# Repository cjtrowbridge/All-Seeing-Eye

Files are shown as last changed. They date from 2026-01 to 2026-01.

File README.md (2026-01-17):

License: 

# All-Seeing-Eye Design Document
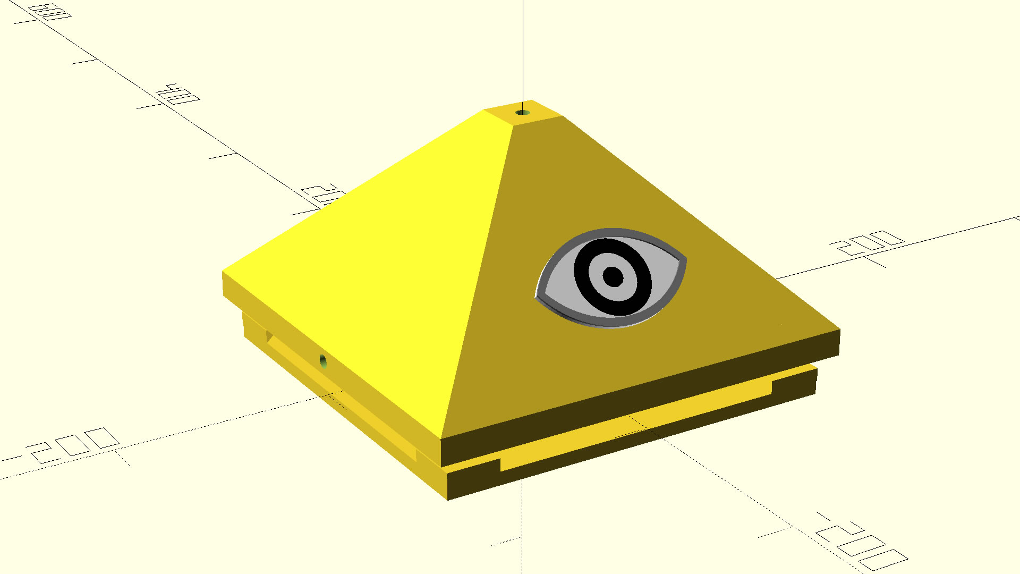
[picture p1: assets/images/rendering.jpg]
All-Seeing Eye Rendering


A 3d printed structure to contain broad spectrum sub-ghz meshtastic VLBI elements

## 1. Broader System Architecture

The overall system is composed of two primary node types:

* **SDR Node**

  * Performs wideband spectrum sensing
  * Handles coordination and task delegation
  * Synthesizes composite spectrum and RSSI bitmaps

* **All-Seeing Eye** Nodes (ESP32 + CC1101)

  * Perform distributed, narrowband RSSI sensing
  * Contribute localized observations to the global view

By correlating RSSI bitmaps from multiple perspectives, the system can simultaneously determine **where many RF broadcasts each originate from, in real time**. Complete spectral visibility emerges from the correlation of many limited observers.

This design document focuses on the **All-Seeing Eye Node** as a physical and conceptual artifact within this broader architecture.

This project is intended to operate as a **VLBI (Very Long Baseline Interferometry) Cluster**. While individual nodes provide utility, the core value proposition is the synchronized collaboration of multiple distributed nodes to triangulate signals and build high-fidelity spectrum maps.

To support synchronized sampling, nodes establish a shared wall-clock using **SNTP/NTP**. This time baseline enables cluster-wide coordination (e.g., aligned scan windows) and is a prerequisite for higher-order ranging and consensus behaviors.
When running spectrum scans, nodes should align on UTC boundaries and only sweep when `utc_seconds % 10 == 0` to keep samples phase-aligned across the cluster.

## 2. Regulatory & Operational Posture

**PASSIVE OBSERVATION ONLY**:
The "All-Seeing Eye" is designed exclusively as a **Passive Reception Device**. 
*   The default firmware strictly disables any transmission capabilities on the CC1101 radio to ensure compliance with local RF regulations (FCC/CE). 
*   The device listens, measures, and reports. It never transmits, jams, or interferes.
*   *Note: While the hardware supports TX, enabling it requires manual firmware modification by the user, who assumes all legal liability.*

---

## 3. Naming Decisions

* **All-Seeing Eye** — distributed RF observer

The term *All-Seeing Eye* is used **literally and technically**, describing emergent total visibility of the RF spectrum derived from correlated partial observations, not from a single privileged vantage point.

---

## 4. Physical Design Specifications (Prototype)

For the initial prototype, the enclosure must meet the following precise physical specifications to be modeled in 3D:

### 4.1 Base Geometry
*   **Structure**: A hollow square prism.
*   **Dimensions**: 8 inches x 8 inches (Outer footprint) - *Updated from 4" in v1.1*.
*   **Height**: 0.5 inches.
*   **Wall Thickness**: 0.25 inches.
*   **Notes**: This forms the foundation upon which the pyramid sits.

### 4.2 Pyramid Geometry
*   **Structure**: A hollow 4-sided pyramid sitting directly atop the base.
*   **Material Compatibility**: The shell must be printed in **Semi-Transparent** material (PETG/PLA) to allow internal LED diffuse lighting to be visible externally without physical apertures.
*   **Slope**: Faces must be angled at 45 degrees.
*   **Wall Thickness**: 0.25 inches.
*   **Front Face**: Blank (Eye Symbol is a separate attachment).
*   **Top**: Truncated flat top.
    *   The flat top accommodates a central SMA connector hole.

### 4.3 Base Plate (Bottom Lid)
*   **System**: A separate 0.25" thick plate that snaps into the bottom of the shell.
*   **Alignment**: Includes four corner alignment tabs (triangles) that fit inside the shell walls.
*   **Latching Mechanism**: Magnetic Latch System.
    *   **Magnets**: Uses 8x 6x3mm round magnets (4 in shell, 4 in lid).
    *   **Magnet Placement**: Magnets are installed in internal recesses (blind holes) so they never touch directly. There is a ~1mm plastic bridge separating them.
    *   **Shell Side**: Corner blocks inside the base rim hold magnets facing down.
    *   **Lid Side**: Alignment tabs hold magnets facing up.
    *   **Superglue**: Magnets are secured in their recesses with superglue or epoxy.

### 4.4 Clearances
*   The entire assembly is hollow.
*   Internal thickness of walls is consistent (0.25 inch).

### 4.5 Eye Symbol (Attachment)
*   **Design**: A separate visual artifact attached to the front face.
*   **Style**: Minimalist "All-Seeing Eye" (Almond shape + Pupil).
*   **Dimensions**: 3 inches wide x 1.75 inches tall.
*   **Mounting**: Adhered to the front 45-degree face.

---

## 5. Connectivity & Interface Layout

The connector ports are distributed across the faces of the **Base Prism** and the **Pyramid Top**.

### 5.1 Top Interface (Pyramid Apex)
*   **Connector**: VNA / Sensing SMA.
*   **Placement**: Centered on the flat, truncated top of the pyramid.
*   **Requirements**: Through-hole sized for standard SMA bulkhead. Clearance for cable attachment.

### 5.2 Base Interfaces
The base prism has four faces. The layout is as follows:

*   **Front Face**: 
    *   **Status**: Blank / Uninterrupted.
*   **Rear Face**:
    *   **Connector**: USB / Power.
    *   **Details**: A cutout or hole reaching the bottom edge of the base, allowing a USB cable to pass under/into the unit for power and control.
*   **Left Face**:
    *   **Connector**: 2.4GHz Wi-Fi Antenna (SMA).
    *   **Details**: Through-hole for SMA bulkhead. Ensure internal clearance for the nut and external clearance for antenna rotation.
*   **Right Face**:
    *   **Connector**: Meshtastic Node Antenna (SMA).
    *   **Details**: Through-hole for SMA bulkhead. Ensure internal clearance for the nut and external clearance for antenna rotation.

This layout separates sensing from networking both **electrically and visually**, while maximizing RF isolation within a compact enclosure.

---

## 6. Lighting Design

Lighting is used to convey **latent awareness**, not alerts or activity.

### Principles

* Dim, indirect, constant illumination
* No flashing, blinking, or RGB cycling
* Light is a side effect of perception, not a signal

### Lighting Layers

* **Eye Glow**: Internal RGB LED (ESP32) diffuses through the **semi-transparent shell material**. No physical hole is required.
* **Edge Leakage**: Subtle light escaping along seams or edges
* **Base Halo (optional)**: Soft downward glow to create a floating artifact effect

Lighting behavior is slow, restrained, and continuous, reinforcing the sense that the node is always perceiving.

---

## 7. Optional Hardware Components

While the core functionality is provided by the ESP32 and CC1101, additional modules can establish the node as a precise reference point in the VLBI network.

### GPS Module
*   **Component**: **[GY-NEO6MV2 (u-blox NEO-6M)](https://amzn.to/3NpCHRz)**
*   **Purpose**: Provides accurate geolocation and precise time-synchronization for signal timestamping.
*   **Precision**: +/- 2.5m.
*   **Integration**: Can be mounted internally on the base plate or adhered to the inner wall.

---

## 8. Geolocation Techniques

This section details methods for determining the positions of dispersed nodes.

### 8.0 Geolocation Core Service (Planned)
The firmware will maintain a core geolocation service that fuses evidence over time (GPS, WiFi, BLE, RF, mesh) into a single estimate. The service exposes a summarized `geolocation` block via `/api/status`, including confidence, fix type (absolute/relative), motion state, and last-updated time. This is the anchor point that BLE ranging and other sensors will feed into.

### 8.1 Native Approach (No GPS)
This method utilizes the core ESP32+CC1101 hardware to estimate location without dedicated GPS modules. It relies on a "Spring-Mass" or "Elastic Map" concept.

**1. Relative Positioning (Multidimensional Scaling)**
*   **Concept**: Every node broadcasts packets to every other node to measure pairwise RSSI (Signal Strength).
*   **Processing**: These values are fed into a **Multidimensional Scaling (MDS)** algorithm. The algorithm treats RSSI values as "springs" (distances) and unfolds the graph to find the geometric shape that best satisfies the signal constraints.
*   **Result**: A relative 2D map of where nodes are sitting relative to each other (e.g., "Node A is 5 meters left of Node B").
*   **Accuracy**: ~3–10 meters relative precision.

**2. Absolute Anchoring (WiFi Fingerprinting)**
*   **Concept**: To pin this floating relative map to the real world, ESP32s scan for all nearby WiFi Access Point BSSIDs.
*   **Processing**: This data is resolved via Geolocation APIs (e.g., Google/Mozilla) to approximate latitude/longitude.
*   **Result**: Provides an absolute "anchor" for the cluster.
*   **Accuracy**: ~15–30 meters.

**Caveats**: 
*   This approach is essentially an estimation.
*   RSSI is easily distorted by obstacles (multipath fading), which can warp the calculated geometry.
*   WiFi geolocation depends entirely on the density of known networks in the area.

### 8.2 Precision Approach (GPS)
The preferred alternative is installing the optional **GY-NEO6MV2 GPS Module** (see Section 6).
*   **Accuracy**: +/- 2.5m (Absolute).
*   **Reliability**: Independent of WiFi availability and unaffected by RF multipath distortion.

### 8.3 Role of the Single RTL-SDR
While a single RTL-SDR node cannot perform Time Difference of Arrival (TDOA) multilateration (which requires 3+ synchronized anchors), it plays a support role:
*   **Calibration**: Use the SDR to monitor transmission power of the nodes, normalizing "hot" transmitters that would otherwise skew RSSI distance calculations.
*   **Pseudo-Doppler (Advanced)**: With a custom antenna-switching add-on, the single SDR can perform Direction Finding to determine the Angle of Arrival (AoA), adding bearing lines to the location solution.

---

### 8.4 VLBI / TDOA Possibilities (Future Scope)
While the current prototype focuses on RSSI, the project name "All-Seeing Eye" references **VLBI (Very Long Baseline Interferometry)** concepts.

*   **TDOA Viability**: Time Difference of Arrival (TDOA) requires extremely precise nanosecond-level clock synchronization across nodes.
    *   **ESP32 Limitations**: The standard ESP32 clock is not stable enough for fine-grained TDOA on its own.
    *   **Non-Coherent Operation**: Since the nodes are not phase-coherent (they don't share a local oscillator), standard interferometry is impossible.
*   **Large Baseline Approach**: If nodes are separated by significant distances (kilometers), the timing requirements relax slightly for macroscopic TDOA.
    *   **GPS PPS**: Adding the **GPS Module (Section 6)** provides a **Pulse Per Second (PPS)** signal. This can discipline the local clocks to within microsecond accuracy.
    *   **Feasibility**: With GPS-disciplined timestamps, TDOA could potentially resolve location to within ~300 meters (1 microsecond = ~300m light travel time). This allows for "City-Scale" triangulation of powerful signal sources, staying true to the VLBI inspiration despite the lack of phase coherence.

### 8.5 Mesh-Assisted Localization (Opportunistic)
If the node is operating within an active Meshtastic mesh, it can utilize traffic from *other* nodes to determine its own location.

*   **Mechanism**: The node listens for position packets from nearby Meshtastic nodes that *do* have GPS fixes.
*   **Calculation**: By measuring the RSSI of the incoming packet and extracting the GPS coordinates from the payload, the node treats the sender as a "Beacon" or "Anchor".
*   **Trilateration**: With signals from 3+ distinct GPS-enabled peers, the node can estimate its position based on expected signal fade (Path Loss Models).
*   **Single-Hop Constraint**: This technique relies on **direct (single-hop)** reception. Use of RSSI from relayed packets would result in calculating distance to the repeater, not the original sender, leading to gross errors. The system must verify the packet has not been hopped before using it for ranging.

### 8.6 BLE Ranging & Live Topology Consensus
To complement RF triangulation, newer iterations of the system employ BLE (Bluetooth Low Energy) for high-resolution proximity detection within the cluster itself.

*   **Stationarity Detection**: By constantly monitoring the RSSI of known peers over BLE, the cluster can detect if the configuration is static or in motion. Stable RSSI values over N minutes imply a stationary deployment, triggering higher-precision, longer-integration RF tasks.
*   **Short-Range Ranging (<20m)**: Standard WiFi/Sub-GHz RSSI is noisy. BLE advertising provides a separate, dedicated channel for "Ranging Beacons".
    *   **Consensus**: If Node A sees Node B at -40dBm and Node C at -85dBm, and Node B sees Node C at -70dBm, the cluster can solve for the relative geometry of the triangle {A,B,C}.
*   **Implementation**: This runs as a background task (`SystemIdlePlugin`) on the ESP32 core, independent of the CC1101 radio, ensuring it does not interrupt long-range spectral monitoring.

---

## 9. Overall Intent

The All-Seeing Eye Node is designed as:

* a sensing instrument
* a symbolic artifact
* a field-deployable system component

The system observes **broadcast signals, not people**. Power derives from distribution, correlation, and persistence rather than authority or control.

The object is meant to feel present, inevitable, and quietly capable — something you notice after it has already been there.

---

## 10. Locked Concepts

* **Names**: SDR Node, All-Seeing Eye Node, All-Seeing Eye View
* **Form**: Pyramidal structure on a raised square base.
* **Function**: Distributed RF visibility through correlated RSSI sensing
* **Aesthetic**: Ominous, restrained, archetypal, intentional

---

## 11. Fabrication & Build Pipeline

The physical enclosure is designed programmatically using **OpenSCAD**. This ensures that all dimensions, clearances, and tolerances can be adjusted parametrically and versioned as code.

### Prerequisites
*   **OpenSCAD**: Download and install from [openscad.org](https://openscad.org/).

### Shopping List
* Sparkly semi-transparent purple PLA filament ([$19.99](https://amzn.to/3Yy0ZLC))
* I used an AD5M Pro 3D printer which is 10/10. Fully enclosed and filtered. 220x220x250mm build volume. Very easy to use. ([$379](https://amzn.to/4aUHjsQ))
* ESP-32 3-pack with IPX MHF1 connector ([$17.99](https://amzn.to/3YyJqLl))
* CC1101 module 3-pack ([$22.99](https://amzn.to/4qEJl4S))
* IPX MHF1 to SMA Cable 5-pack ([$8.29](https://amzn.to/3NbLDdm))
* Jumper wires (male-female) (there are infinite options here but there are what i used) ([$6.98](https://amzn.to/4qsRIkg))
* Heltec v3 Meshtastic Node (optional, any meshtastic node with IPX MHF1 connector will do) ([$21.99](https://amzn.to/49MXC9Y))
* GY-NEO6MV2 GPS Module (optional) ([$9.99](https://amzn.to/3NpCHRz))
* 2.4ghz wifi antenna 4-pack (optional, any wifi antenna with SMA connector will do) ([$8.69](https://amzn.to/4szIt3d))
* 915mhz antenna 2-pack (optional, any 915mhz antenna with SMA connector will do) ([$9.99](https://amzn.to/3LGUaV7))
* SMA Extensions 2-pack (optional, but its going to hard to fit everything without these [$6.99](https://amzn.to/45Ou0Xd))
* Self-advesive breadboard (optional) [$8.99](https://amzn.to/49mhwbJ)

### Source Files
*   Design files are located in the `3d models/design/` directory.

#### Core Files
*   **Shell (Blank)**: `3d models/design/all-seeing-eye.1.6.scad` (Magnetic Latch System, Blank Face).
*   **Base Plate**: `3d models/design/base-plate.1.0.scad` (Matching Magnetic Lid).
*   **Eye Symbol**: `3d models/design/eye-symbol.1.0.scad` (Separate print).

#### Combined Variants
*   **Combined Shell**: `3d models/design/combined-1.1.scad` (Shell + Eye formed as one piece. **Includes transparency cutout** behind the eye for LED visibility).

#### Visualization
*   **Assembly**: `3d models/design/assembly.1.0.scad` (Visualization only).

### Printing Strategies
You can choose between two assembly methods:

1.  **Combined Print (Recommended)**: 
    *   Print `combined-1.1.stl` and `base-plate.1.0.stl`.
    *   This provides a robust, single-piece shell with the eye symbol pre-integrated and optimized for transparency.
2.  **Separate Parts**:
    *   Print `all-seeing-eye.1.6.stl` (Blank Shell), `eye-symbol.1.0.stl`, and `base-plate.1.0.stl`.
    *   Glue the eye symbol onto the front face manually.
    *   *Note*: This method does not have the transparency cutout behind the eye, so the LED glow may be dimmer.

### Generating 3D Printable Files (STL)
To generate the STL files for printing:

1.  Run the automated build script:
    ```cmd
    cd "3d models"
    .\build.bat
    ```
2.  The script will automatically detect OpenSCAD and compile all versions found in the `design/` folder.
3.  Output STL files will be placed in the `build/` directory.

### Print Preview & Estimates
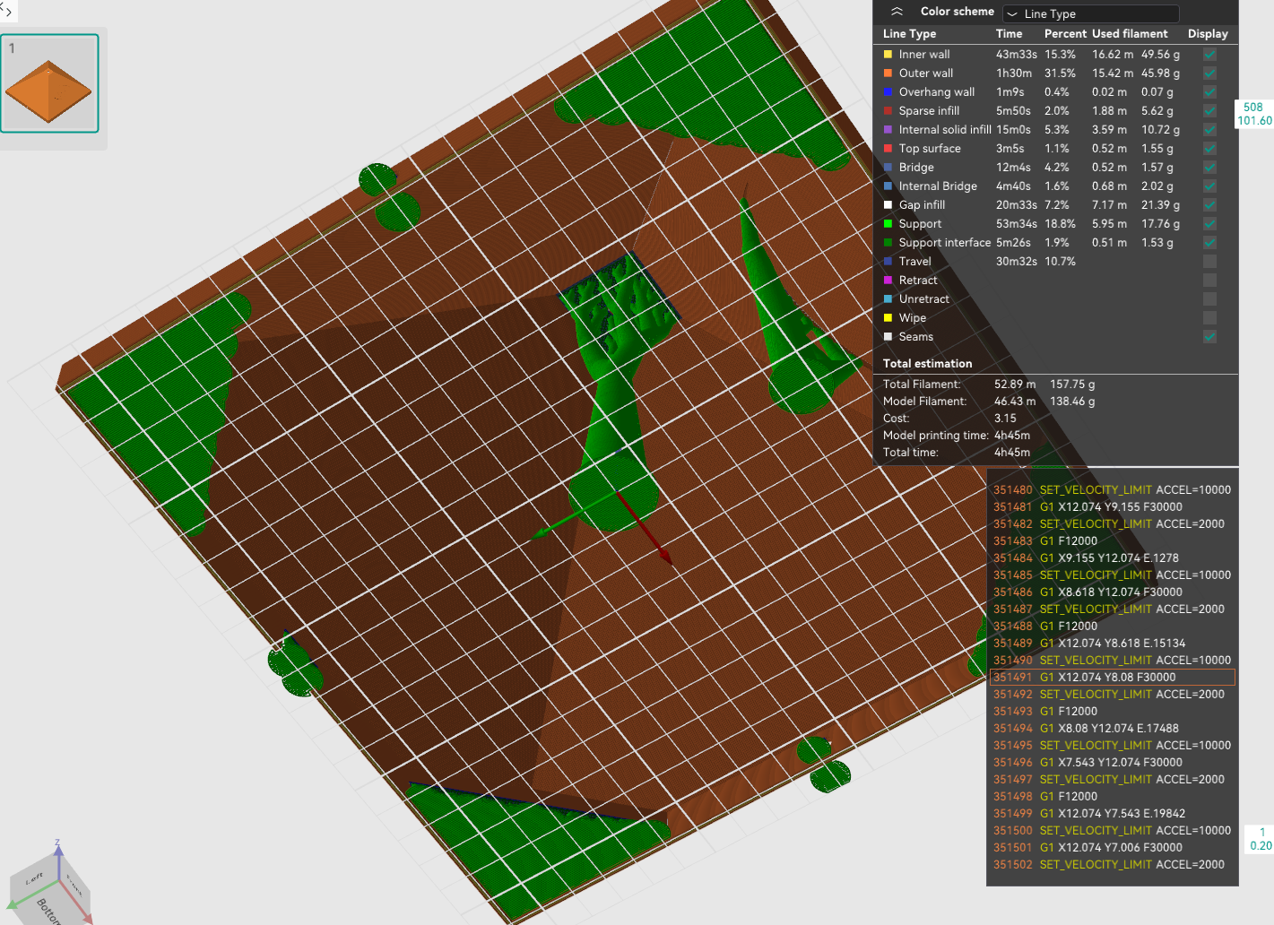
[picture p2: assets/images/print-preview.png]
Print Preview


(Note: Estimates below are approximate place holders based on 15% infill and standard PLA settings with tree support).

*   **Print Time**: 4 hours, 45 minutes
*   **Material Usage**: ~157.75g
*   **Material Cost**: ~$3.15 (at $19.99/kg)

---

## 12. Wiring Guide (ESP32-S3 N16R8)

The system uses an **ESP32-S3-WROOM-1 N16R8** development board. This board has a different pinout than the classic ESP32.

The recommended wiring uses the **Left Header** almost exclusively to keep cabling tidy, and because thats all you can access in a standard breadboard with a package this size. It utilizes the default hardware SPI pins for the S3 (FSPI).

| CC1101 Pin | Pin Name | Function | ESP32-S3 Pin | Location on Board |
| :--- | :--- | :--- | :--- | :--- |
| 1 | **GND** | Ground | **GND** | Bottom Left (G) |
| 2 | **VCC** | Power (3.3V) | **3V3** | Top Left (Pin 1 or 2) |
| 3 | **GDO0** | Interrupt (Differs from v1) | **GPIO 4** | Left Side (Top) |
| 4 | **CSN** | Chip Select | **GPIO 10** | Left Side (Middle, marked FSPICS0) |
| 5 | **SCK** | SPI Clock | **GPIO 12** | Left Side (Middle, marked FSPICLK) |
| 6 | **MOSI** | Master Out | **GPIO 11** | Left Side (Middle, marked FSPIIO5) |
| 7 | **MISO** | Master In | **GPIO 13** | Left Side (Middle) |
| 8 | **GDO2** | Interrupt 2 (Optional) | **GPIO 5** | Left Side (Top) |

### Additional Hardware Notes
*   **Onboard RGB LED**: The built-in status LED on this specific board is on **GPIO 47** (or 48 on some variants).
*   **Power & Programming**: 
    *   **Right Port (UART)**: Use this for standard programming and serial monitoring. It runs through the onboard CH343P chip for a reliable connection.
    *   **Left Port (USB)**: This is the native ESP32-S3 USB (OTG) port. It can power the board, but is used for advanced USB device emulation.
*   **Antennae**: Ensure the CC1101 antenna is connected before powering on the device to avoid damage to the PA (Power Amplifier).

---

## 13. Version History & Development Log

This section documents the iterative design process from initial concept to the current printable shell.

### Current Version: v1.6 (Magnetic System)
*   **Status**: Ready for Print.
*   **Description**: Full magnetic latching enclosure system.
*   **Components**:
    1.  **Shell (v1.6)**: Added internal corner blocks with blind holes for 6x3mm magnets.
    2.  **Base Plate (v1.0)**: New bottom lid with alignment tabs and matching magnet recesses.
    3.  **Eye Symbol (v1.0)**: Separate "Vesica Piscis" style eye attachment.
    4.  **Combined Variant (v1.0)**: Alternate shell model with the Eye Symbol already fused to the front face (single print).
*   **Material**: Shell MUST be printed in **Semi-Transparent** material for checking internal status LEDs without opening.

### Development Milestones

*   **v1.5**: Clean Shell.
    *   Reverted complex internals to validate form factor.
    *   8-inch base, 45-degree slope.

*   **v1.3 - v1.4**: Internal Mounting Experiments (Deprecated).
    *   Analyzed ESP32-S3-WROOM-1-N16R8 dimensions via photos.
    *   Measured LED alignment offsets (-6mm X, +18mm Y) to center the LED on the pyramid face.
    *   Designed candidate internal brackets for "flush face" mounting.
    *   *Decision*: Complexity of supporting floating internal rails was high; reverted to clean shell (v1.5) to ensure printability first.

*   **v1.2**: Geometry Fixes.
    *   Identified and fixed a bug where the internal hollow void was cutting completely through the roof.
    *   Adjusted the inner pyramid height to leave a solid 0.25" roof for the top SMA connector.

*   **v1.1**: Scaling Up.
    *   Increased base size to 8 inches to accommodate larger internal volume requirements.
    
*   **v1.0**: Initial Parametric Design.
    *   Established the OpenSCAD codebase.
    *   Defined the core "Base + Pyramid" geometry.
    *   Initial size: 4-inch base.

### Hardware Research (ESP32-S3)
*   **Device**: ESP32-S3-WROOM-1-N16R8 Dev Board.
*   **Dimensions**: 58mm x 28mm (PCB footprint).
*   **LED Position**: The RGB LED is offset from the center.
    *   **X-Offset**: ~6mm left of PCB center.
    *   **Y-Position**: ~18mm from the USB edge.
*   **Future Integration**: Future enclosure revisions will incorporate a mounting sled or clip that aligns this specific LED location with a window in the pyramid face.

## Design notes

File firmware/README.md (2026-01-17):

# Developer Protocol & Tips
**Critical instructions for Agent/Devs to avoid build loops:**

1.  **Build System Limitations**: 
    -   Arduino's build system struggles with complex relative paths in `#include`. 
    -   **Rule**: Keep all header files flat in `src/` (e.g., `src/CC1101Plugin.h`, not `src/plugins/radios/CC1101Plugin.h`). Complexity is managed by namespaces, not folders.

2.  **Build Automation**:
    -   **Never** manually run `arduino-cli` commands in the terminal. The syntax is brittle on PowerShell.
    -   **Rule**: Always use `.\upload_ota.bat`. It handles library paths and OTA upload arguments reliably.

3.  **Concurrency (Dual Core)**:
    -   Core 0 (System) and Core 1 (Plugin) share resources.
    -   **Rule**: Always use `xSemaphoreTake` with a timeout (e.g., `pdMS_TO_TICKS(100)`) when accessing shared objects (like the Plugin pointer). Never block indefinitely.

4.  **Logging & Debugging**:
    -   **Rule**: Do NOT create ad-hoc text files (e.g., `output.txt`, `debug.txt`) in the repo. They clutter the git history.
    -   **Rule**: If you must dump output to a file, use the `.log` extension (e.g., `build.log`), as these are globally ignored by `.gitignore`.
    -   **Rule**: Log timestamps use the configured device timezone (NTP-synced) and fall back to Unix epoch seconds before sync. Startup head logs include the applied timezone.

5.  **Regulatory Compliance (NO TX)**:
    -   **Rule**: The CC1101 radio must be operated in **RX (Receive) Mode ONLY**.
    -   **Rule**: Do not commit any code that initializes the radio for transmission (TX) or enables broadcasting. The default firmware is passive.

6.  **WebUI Polling Optimization**:
    -   **Rule**: The WebUI must only poll `/api/status` on a regular interval (e.g., 2s).
    -   **Rule**: `/api/status` must embed the latest **Logs** (last N lines) and **Peer List** to support this single-call architecture.
    -   **Reason**: The ESP32 single-core network stack struggles with concurrent HTTP requests. reducing connection overhead improves responsiveness.

# Hardware Abstraction Layer (HAL)

The firmware is designed to run on diverse hardware configurations. The `HAL` class manages driver initialization and sets Capability Flags based on Power-On Self Tests (POST).

The System Kernel uses these flags to determine which tasks can be run. These flags are exposed via `/api/status` so external agents can make informed decisions.

*   `cc1101`: (bool) True if the Sub-GHz radio was detected and initialized successfully on the SPI bus.
*   `gps`: (bool) True if a dedicated hardware GPS module is connected (UART).
*   `meshtastic`: (bool) True if a LoRa radio is available for Meshtastic interoperability.

# Cluster Task Coordination

The cluster coordinates tasks using **status-based alignment**. Nodes do **not** push task payloads to peers. Instead, each node advertises its desired task in `/api/status`, and peers align themselves by observing the network.

*   **Desired Task**: `/api/status.desired_task` contains the staged task payload.
*   **Start Gate**: `/api/status.start_requested` signals when execution should begin.
*   **Alignment Rule**: The WebUI enables the Start button when `/api/peers` shows that all online peers have aligned to the desired task.
*   **Memory**: Results are ephemeral and cleared when the task changes.

---

# Roadmap

## Phase 1: Core Framework (Completed)
- [x] Basic ESP32-S3 Board Support
- [x] Double-Buffered Plugin Architecture (Core 0 vs Core 1)
- [x] RingBuffer for high-speed logging
- [x] OTA via `espota`
- [x] Webpack pipeline for embedded `index.html`

## Phase 2: Hardware Drivers (Completed)
- [x] CC1101 SPI Integration
- [x] RSSI Reading & Tuning
- [x] Circular Buffer Logging

## Phase 3: Web Dashboard (Completed)
- [x] Basic SPA structure
- [x] WebSocket/Poll-based logs
- [x] **UI Refactor v2 (Jan 2026)**: 
    -   Implemented 3-column "Desktop" layout (Environment / Task List / Execution).
    -   Center column functions as the primary Control interface with a categorized **Task List**.
    -   Tasks are grouped by Plugin (human-readable headers) for better navigability.
- [x] **Navbar Enhancements**: Cluster Status with "Sparkle" indicators.

# Web Interface Architecture

## Layout System
The WebUI (`index.html`) uses a responsive grid layout that adapts between mobile and desktop views:

1.  **Environment (Left)**:
    -   **Cluster Tree**: Shows local and remote nodes, grouped by cluster name.
    -   **Topology Map**: Force-directed graph of the mesh network.
    -   **Logs**: Dual-tab monitor for `Tail` (Live) and `Head` (Boot) logs.

2.  **Controls (Center)**:
    -   **Task List**: The primary catalog of available operations (Plugins).
        -   Grouped by **Plugin Name** (e.g., "System", "Spectrum Analyzer").
        -   Tasks are defined in `PluginManager.cpp` and served via `/api/task`, including input schemas.
    -   **Device Config**: Settings for Hostname, Identity, Timezone, and LED.

3.  **Workspace (Right)**:
    -   **Input Form**: Dynamically generated based on the selected task's requirements.
    -   **Execution State**: Shows live status, spinners, and timers during task execution.
    -   **Results**: (Planned) Dedicated view for post-mission data analysis.

## Development Workflow
The WebUI is a single-file application (`firmware/web/index.html`). To modify it:

1.  Edit `firmware/web/index.html`.
2.  Run `pack_web.py` (in `firmware/`) to compress the HTML into `WebStatic.h` (Gzip + Hex).
3.  Compile and upload firmware using `upload_ota.ps1`.

**Note**: The ESP32 does not serve the file from a filesystem; it serves the byte array from flash memory for speed and reliability.

# Web Interface & Topology Map

The Web Dashboard (`/index.html`) includes a live **Topology Map** visualizing the mesh network.

## Legend Reference

| Element | Color | Description |
| :--- | :--- | :--- |
| **Self (Dot)** | `Cyan (#03dac6)` | The node currently hosting the web interface. |
| **Peer (Dot)** | `Purple (#bb86fc)` | A peer node that is currently **Online** and responsive. |
| **Offline (Dot)** | `Gray (#444)` | A peer node that has timed out (stale) or is unresponsive. |
| **LAN Link** | `Blue (#2196F3)` | A direct network connection (WiFi or Wired) established via mDNS discovery. |
| **Ranging** | `Red (#cf6679)` | (Planned) A physical RF ranging measurement between nodes. |

## Interaction

*   **Click Node**: Navigate to that node's WebUI (`http://[hostname].local`).
*   **Hover**: View tooltip (currently hostname).
*   **Physics**: The map uses a force-directed graph (d3-style) where nodes repel each other but are bound by links.

# Roadmap Continued

## Phase 4: VLBI Clustering (Backend Completed)
- [x] **Core Logic**: Default Kernel state is now `SystemIdle` (POST -> Idle).
- [x] **Unique Identity**:
    - [x] Hostnames: `allseeingeye-{hexid}.local` (from MAC address).
- [x] **Time Synchronization (Foundation)**:
    - [x] **SNTP Integration**: 
        - [x] Configure `configTime` with `pool.ntp.org` and proper timezone handling (Los Angeles).
        - [x] Implement `Kernel::isTimeSynced()` validator (Checks Year > 2025).
        - [x] Enable time zone configuration via `/api/config` (string, e.g., "America/Los_Angeles") and persist in NVS
        - [x] Map common IANA timezones to POSIX TZ rules for localtime/log formatting.
        - [x] Make timezone editable in webui under device tab.
    - [x] **API Visibility**: 
        - [x] Add `time` (Unix Epoch) and `ntp_sync` (bool) to `/api/status`.
    - [x] **Drift Management**: 
        - [x] Configure re-sync interval (1hr).
- [x] **Discovery Protocol**:
    - [x] **Zero-Conf**: mDNS (`_allseeingeye._tcp`) auto-discovery.
    - [x] **Subnet Scanning**: Automatically scans local /24 subnet (1-254) if isolated.
    - [x] **Passive Discovery**: Intercepts requests to `/api/peers` to find new neighbors.
    - [x] **Negative Caching**: Ignores non-peer IPs for 12h to reduce network noise.
- [x] **Cluster Management**:
    - [x] Nodes advertise `cluster` text record in mDNS.
    - [x] Clusters visualized in Web UI Tree View.
    - [x] Configurable **Cluster Name** and **Ignore Hours**.

## Phase 5: Task-Oriented Architecture (In Progress)
The system has pivoted from always-on background services to an On-Demand Task Architecture to respect ESP32 resource constraints.

### 5.1 The Task Registry (Framework)
- [x] **Plugin Framework**:
    - [x] `ASEPlugin`: Abstract base class implementation.
    - [x] `PluginManager`: Handles loading/unloading and exclusive resource locking.
    - [x] **Discovery API (`GET /api/task`)**: Returns catalog of available tasks.
        - [x] Grouped by Plugin Name.
        - [x] Includes Task ID, Description, Link, and `inputs` schema.
- [x] **Task Execution API**:
    - [x] `POST /api/task/{taskId}`: Submits parameters and starts execution.
        - [x] **UX Flow**: Response replaces the UI "Working" container with results table/heading.

### 5.2 WebUI Implementation (Task Runner)
The Web Interface must dynamically render available tasks and handle the execution flow.
- [x] **Catalog Rendering (Navigation)**:
    - [x] Fetch catalog from `GET /api/task`.
    - [x] Render groupings by Plugin Name (e.g., `<h3>BLE Ranging</h3>`).
    - [x] Render buttons for each task under the appropriate heading.
- [x] **Dynamic Form Generation (Task Panel)**:
    - [x] **Action**: Clicking a task button reads the `inputs` schema from the cached `/api/task` catalog.
    - [x] **Render**: Clear the Task View (Right/Center Column) and generate an HTML Form based on the schema.
    - [x] **Validation**: Ensure required fields are marked and validated before submission.
- [x] **Execution State**:
    - [x] **Submission**: On form submit, serialize data to JSON.
    - [x] **UI Update**: Remove Form -> Display "Deploying..." / Spinner message.
    - [x] **Request**: Send `POST /api/cluster/deploy` with task payload.
- [x] **Result Rendering**:
    - [x] **Execution**: Start is enabled only after cluster alignment; UI calls `POST /api/cluster/start`.
    - [x] **Report View**: UI polls `/api/report` and renders JSON output.

### 5.3 Geolocation (On-Demand Plugin)
Moved from background service to requested task.
- [ ] **Features**:
    - [ ] `Fix Acquisition`: Power up GPS (if avail) or run WiFi/BLE anchor scan. High power usage.
    - [ ] `Motion Baseline`: Short sampling period to detect movement vectors.
    - [ ] `Confidence Recalibration`: Re-assess cached location vs new signals.
- [ ] **Architecture**:
    - [ ] Plugin owns the Geolocation State.
    - [ ] Results persist in `/api/status` (cached) after task completes.

---

# Phase 6: Core Plugins (Detailed Plan)
The following plugins will be implemented using the new Task Registry framework.

- [ ] **6.1 BLE Ranging Plugin**
## 6.1 BLE Ranging Plugin
*   **Heading**: BLE Ranging
*   **Tasks**:
    1.  [ ] **Peer Ranging**:
        *   [ ] *Endpoint*: `/api/task/ble-ranging/peer`
        *   [ ] *Inputs*: Duration (ms), Target Peer (Optional).
        *   [ ] *Action*: Active scan + RSSI history logging.
    2.  [ ] **Device Survey**:
        *   [ ] *Endpoint*: `/api/task/ble-ranging/survey`
        *   [ ] *Inputs*: Scan Window (ms), Filter (Manufacturer/Service).
        *   [ ] *Action*: Lists all nearby BLE MACs and payloads.

- [ ] **6.2 Geolocation Plugin**
## 6.2 Geolocation Plugin
*   **Heading**: Geolocation
*   **Tasks**:
    1.  [ ] **Fix Acquisition**:
        *   [ ] *Endpoint*: `/api/task/geolocation/fix`
        *   [ ] *Inputs*: Timeout (ms), Desired Accuracy (m).
        *   [ ] *Action*: Aggregates GPS + WiFi anchors. Returns Lat/Lon/Alt.
    2.  [ ] **Motion Baseline**:
        *   [ ] *Endpoint*: `/api/task/geolocation/motion`
        *   [ ] *Inputs*: Sample Duration (s).
        *   [ ] *Action*: Detects if node is stationary or moving.
    3.  [ ] **Confidence Recalibration**:
        *   [ ] *Endpoint*: `/api/task/geolocation/recalibrate`
        *   [ ] *Action*: Checks current fix against new evidence without full acquisition.

- [ ] **6.3 RF Diagnostics Plugin**
## 6.3 RF Diagnostics Plugin
*   **Heading**: RF Diagnostics
*   **Tasks**:
    1.  [ ] **Noise Floor Check**:
        *   [ ] *Endpoint*: `/api/task/rf-diag/noise`
        *   [ ] *Inputs*: Frequency Band (e.g., 915MHz).
        *   [ ] *Action*: Measures RSSI without sync word/packet logic.
    2.  [ ] **RSSI Snapshot**:
        *   [ ] *Endpoint*: `/api/task/rf-diag/rssi`
        *   [ ] *Action*: Quick sample of ambient energy.
    3.  [ ] **Antenna Health Check**:
        *   [ ] *Endpoint*: `/api/task/rf-diag/antenna`
        *   [ ] *Action*: (Experimental) Heuristic check of VSWR proxy (if HW supports) or signal consistency.

- [ ] **6.4 Spectrum Analysis Plugin**
## 6.4 Spectrum Analysis Plugin
*   **Heading**: Spectrum Analysis
*   **Tasks**:
    1.  [x] **Band Scan**:
        *   [x] *Endpoint*: `/api/task/spectrum/scan`
        *   [x] *Inputs*: Start Freq, Stop Freq, Step.
        *   [x] *Action*: Standard sweep, returns CSV/JSON array of power levels.
        *   [x] *Sync Rule*: Sweep only when `utc_seconds % 10 == 0` so clusters sample in lockstep.
        *   [x] **CC1101 Limits**:
            - [x] Frequency bands: 300–348 MHz, 387–464 MHz, 779–928 MHz
            - [x] Bandwidth: 58–812 kHz
            - [x] Power: -30 to +10 dBm
            - [x] Defaults: 905–928 MHz, 500 kHz, -1 dBm
    2.  [ ] **Peak Hold Sweep**:
        *   [ ] *Endpoint*: `/api/task/spectrum/peak`
        *   [ ] *Inputs*: Duration.
        *   [ ] *Action*: Runs multiple sweeps, keeping only max values.
- [ ] **6.5 Meshtastic Surveillance Plugin**
## 6.5 Meshtastic Surveillance Plugin
*   **Heading**: Meshtastic Surveillance
*   **Tasks**:
    1.  [ ] **Traffic Monitor**:
        *   [ ] *Endpoint*: `/api/task/meshtastic/monitor`
        *   [ ] *Inputs*: Duration, Channel Index.
        *   [ ] *Action*: Logs all seen packets with RSSI/SNR metrics to identify active talkers.
    2.  [ ] **Origin Ranging**:
        *   [ ] *Endpoint*: `/api/task/meshtastic/ranging`
        *   [ ] *Inputs*: Target Node ID.
        *   [ ] *Action*: Analyzes signal strength and hop counts of incoming messages to estimate physical proximity.
    3.  [ ] **Network Traceroute**:
        *   [ ] *Endpoint*: `/api/task/meshtastic/trace`
        *   [ ] *Inputs*: Target Node ID.
        *   [ ] *Action*: Performs an active traceroute to map the hop path and locate the node within the mesh topology.

---

## Phase 7: Telemetry & Peripheral Expansion
- [ ] **Hardware Probe**:
    - [ ] **Serial Probe**: Detect attached GPS (NMEA) or Meshtastic node on boot.
    - [ ] **I2C Scanner**: Auto-detect connected environment sensors (Temp, Air Quality, Geiger).
- [ ] **Meshtastic Integration**:
    - [ ] Serial API Client: Send/Receive messages via attached mesh node.
    - [ ] Configurable Channel: "Announce to Public" vs "Private Group".
- [ ] **Universal Telemetry Bus**:
    - [ ] Standardized polling for arbitrary sensors.
    - [ ] User-configurable announcement intervals.

## Phase 8: Distributed Coordination
- [ ] **Advanced Synchronization (VLBI)**:
    - [ ] **Microsecond Precision**: Track sub-second drift against GPS PPS if available.
    - [ ] **Multi-Transport Sync**: Support sync via Wi-Fi (NTP/PTP) and Meshtastic/LoRa (Custom Beacon).
    - [ ] **Latency Compensation**: Measure RTT (Round Trip Time) to compensate for transmission delay/light-speed lag across different mediums.
    - [ ] **Drift Correction**: Continuous adjustment for local clock drift relative to cluster consensus.
- [ ] **Sychronized Scanning**: Cluster leader designates frequency sweep windows and satart times, based on precisely synchronized time.
    - [ ] **Current Rule**: Spectrum sweeps trigger only when `utc_seconds % 10 == 0`.
- [ ] **TDOA/RSSI Triangulation**: Aggregating data from the cluster to locate the sources of many broadcasts seen simultaneously in a sweep.

## Phase 9: Mesh Parity (Transport Independence)
- [ ] **Transport Agnosticism**: API, Telemetry, and Cluster Control must function transparently over both Wi-Fi and Meshtastic.
- [ ] **Remote Node Equivalence**: A remote node on the mesh should appear in the local Cluster UI just like a Wi-Fi peer.
- [ ] **Bandwidth Optimization**: Protocol compression to support full C2 (Command & Control) over low-bandwidth LoRa links. Since commands are small and text-based, this is highly feasible.

---

# Application Architecture: The VLBI Cluster

## 1. Identity & Discovery (Implemented)
To function as a swarm, every node needs a unique identity on the network.
- **Hostname**: `allseeingeye-XXXXXX`, where `XXXXXX` is the last 3 bytes of the MAC address.
- **Discovery Hierarchy**:
    1.  **mDNS**: Primary method. Multicast announcement of `_allseeingeye._tcp`.
    2.  **Viral/Passive**: When Node A talks to Node B, Node B checks Node A.
    3.  **Brute Force**: If a node has 0 peers, it sequentially scans the entire `.1` to `.254` subnet looking for friends.
- **API Endpoints**:
    -   `/api/peers`: Returns list of known neighbors and their cluster/status.
    -   `/api/ping?target={ip}`: Manual connectivity check.
    -   `/api/config`: Set `cluster` name to move devices between groups.
    -   `/api/status`: Returns system health + current implementation details.

## 2. The concept of "Clustering"
Nodes are not solitary actors; they are members of a **Cluster**.
- **Default State**: Out of the box, all nodes belong to the cluster named `"Default"`.
- **Behavior**: All nodes in a cluster share the same configuration.
- **Formation**: A user can change a node's Cluster Name via the Web UI (or API). That node logically separates and begins listening for peers with the matching Cluster Name.

## 3. The User Interface (Zero-Conf)
The Web UI is hosted on *every* node, but any node can visualize the *entire* cluster.

**Layout Structure:**
1.  **Navbar**:
    *   Branding ("All-Seeing Eye")
    *   Connection Status (Online/Offline)
    *   Cluster Status: `Current Cluster: Default ✨ Working On: SystemIdle ✨`
2.  **Main Content Area (Tabbed View)**:
    *   **Clusters**: Tree view of all clusters and nodes (Auto-Grouping).
    *   **Task View**: Current operation controls (Scanner/Monitor) and task status.
    *   **Logs**: Real-time scrolling system logs (RingBuffer backed).
3.  **Visualization Panel**: Persistent spectrum analysis canvas (bottom of screen).
4.  **Footer**: Telemetry (RAM, Uptime) & Version info.

**Tabs Detail:**
1.  **Cluster Tab (Functional)**:
    -   A Tree View of all announced clusters on the subnet.
    -   `> Default Cluster`
        -   `allseeingeye-a1b2c3` Independent Exploration [Ready]
        -   `allseeingeye-f453a4` Hardware Verification [Working]
    -   `> Scanner-Group-1`
        -   `allseeingeye-224466` RSSI Sweep [Working]

2.  **Node Drill-down**:
    -   Clicking a node opens that device's dashboard.
    -   **Tooltip**: Hovering over a node displays exact task details.

## 4. Task Awareness (New)
The cluster is now "Task Aware".
-   **Default Task**: "Independent Exploration" (System Idle).
-   **Visibility**: All nodes broadcast their current high-level task via `/api/status`. 
-   **Logic**:
    -   `SystemIdlePlugin` -> "Independent Exploration".
    -   `RadioTestPlugin` -> "Hardware Verification".
    -   Future plugins will define their own strings (e.g., "Spectrum Sweep 900-928MHz").
-   **UI Representation**: 
    -   Format: `Hostname | Task Name | [Status]`
    -   Example: `allseeingeye-f453a | RSSI Scanning | [Working]`

## 5. Configuration Fields
To support this, the global configuration structure must expand:
```cpp
struct Config {
    char wifiSSID[32];
    char wifiPass[64];
    // ... current fields ...
    
    // Identity
    char clusterName[32];       // Default: "Default"
    char nodeDescription[255];  // Default: "New Node" or Empty
};
```

## 6. Radio Task Queue Architecture

To support complex operations (scanning, replaying, jamming) while maintaining cluster synchronization, the system moves from a "State Machine" model to a "Scheduled Task" model.

### 6.1 The "Singleton Radio" Problem
The CC1101 radio is a shared resource that cannot do two things at once. It cannot "listen for commands" while "scanning spectrum." Therefore, access must be arbitrated by a **Scheduler**.

### 6.2 Task Object Structure
A `RadioTask` is a self-contained unit of work:
*   **UUID**: Unique identifier for API tracking.
*   **Type**: `CRITICAL` (Startup), `CLUSTER` (Sync), `USER` (API), `BACKGROUND` (Idle).
*   **Plugin**: The specific logic to run (e.g., `Plugin::SpectrumSweep`).
*   **Parameters**: Frequency, duration, target settings.

### 6.3 Lifecycle & Boot Stages
The node does not immediately start "working" on boot. It follows a strict initialization path:

1.  **Phase 1: POST (Power-On Self Test)**
    *   Hardware Init, Filesystem Mount, Config Load.
    *   **Peripheral Probe**: Scan I2C/UART for GPS or Meshtastic nodes.
2.  **Phase 2: Infrastructure**
    *   Wi-Fi Connect, mDNS Start, HTTP Server Start, **NTP Sync**.
    *   **Telemetry Init**: Register any other discovered sensors.
3.  **Phase 3: Startup Queue (Calibration)**
    *   The `Scheduler` is pre-loaded with critical tasks:
    *   1. `RadioHardwareTest`: Ensure SPI comms.
    *   2. `GeolocationScan`: Fingerprint environment.
    *   3. `BackgroundNoiseCalibration`: Measure local RF noise floor.
    *   *(Note: Cluster Discovery is strictly Wi-Fi or Meshtastic Serial; no CC1101 beaconing by default)*.
4.  **Phase 4: Operational Loop**
    *   The Scheduler processes `Queue[0]`.
    *   If Queue is empty -> Insert `IdleTask` (e.g., Background Scan).

### 6.4 API Integration
*   **Enqueue**: Agents/Users `POST` tasks to `/api/queue`.
*   **Preemption**: High-priority tasks (User overrides) push current tasks to `PAUSED` or `ABORTED` state.
*   **Visibility**: `/api/status` returns the current queue depth and next scheduled operation.
*   **Self-Correction**: All API errors must return a `usage` key with a valid JSON example to allow Agents to retry automatically.
*   **Abort to Idle (WebUI)**: The WebUI abort action deploys `system/idle` via `/api/cluster/deploy` followed by `/api/cluster/start` to return the cluster to idle.

## 7. Cluster Network Topology Visualization
The Web UI includes a "Network Map" canvas to visualize the complex relationships between nodes, especially as we introduce varied transport layers (Wi-Fi, Meshtastic, VPN).

### 7.1 The Graph Model
*   **Vertices (Nodes)**: Each node (local or remote) is a vertex.
*   **Edges (Connections)**: A connection represents a visibility path.
    *   *Wi-Fi (LAN)*: Typically a full mesh (everyone sees everyone).
    *   *Meshtastic (LoRa)*: Partial mesh; Node A might see B, but A might not see C directly (multi-hop).
    *   *VPN*: Long-distance links connecting disparate subnets.
    *   *Indirect*: Connections reported by a peer that the local node cannot see directly.

### 7.2 Link Types (Edge Coloring)
The visualization distinguishes different types of relationships between nodes using color coding:

*   **Blue Links (Peer Visibility)**: 
    *   Represent logical visibility (Node A lists Node B in its peer registry).
    *   Length is arbitrary (physics-based force layout).
    *   Derived from `GET /api/peers` data.

*   **Red Links (Ranging Data) [Planned]**:
    *   Will represent physical distance measurements (Time-of-Flight or RSSI-Trilateration).
    *   Length is constrained to scale (e.g., 100px = 1 meter).
    *   Will include a text label showing the raw distance (e.g., "4.2m").

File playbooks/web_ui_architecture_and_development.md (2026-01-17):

# Playbook: Web UI Architecture & Development

## Overview
The All Seeing Eye Web Interface is a Single Page Application (SPA) embedded directly into the ESP32 firmware. It is designed for resource-constrained environments (no external CDNs, minimized payloads) while offering a rich 3-column desktop layout.

## Architecture

### 1. File Structure
*   **Source**: `firmware/web/index.html` (The **ONLY** editable source file).
*   **Build Artifact**: `firmware/AllSeeingEye/src/WebStatic.h` (Generated Gzip + Hex dump).
*   **Deployment**: The artifact is compiled into the C++ binary and served from flash memory.

### 2. Layout System
The UI uses a Responsive Grid System:
*   **Mobile (< 1000px)**: Single column view with bottom navigation tabs (`Cluster`, `Tasks`, `Monitor`).
*   **Desktop (>= 1000px)**: Three simultaneous columns:
    1.  **Environment (Left)**: Network topology, Cluster Tree, and Logs (Tail/Head).
    2.  **Controls (Center)**: 
        *   **Task List**: Catalog of missions grouped by Plugin.
        *   **Device Config**: Identity and hardware settings.
    3.  **Workspace (Right)**: Task configuration forms, execution progress, and results.

### 3. Task Catalog & Dynamic Forms
*   **Source of Truth**: The firmware (`PluginManager.cpp`) defines the catalog and form schemas.
*   **Flow**:
    1.  WebUI fetches `GET /api/task`.
    2.  Loops through the list, creating buttons.
    3.  **Grouping**: Tasks are grouped by the `plugin` field (e.g., "Spectrum Analyzer"). The UI auto-capitalizes and spaces these keys.
    4.  **Selection**: When clicked, the UI generates a form based on the `inputs` array defined in the API response.
        - Inputs support `required`, `default`, `min`, `max`, and `step` to enforce validation and defaults.
    5.  **Cluster Deploy**: On submit, the UI calls `POST /api/cluster/deploy`, polls `/api/status`, and shows an alignment badge (`Aligned X/Y`) before enabling Start.
    6.  **Cluster Start**: When aligned, the UI calls `POST /api/cluster/start` and begins polling `/api/report`.
    7.  **Synchronized Sampling**: Spectrum scans run on UTC-aligned boundaries (`utc_seconds % 10 == 0`) for cluster-wide phase alignment.

## Development Workflow

### Making Changes
1.  **Edit HTML/JS/CSS**: Modify `firmware/web/index.html`.
2.  **Pack Assets**: Run the Python packer script.
    ```powershell
    cd firmware
    .\pack_web.py
    ```
    *This generates `WebStatic.h`. If you skip this, your changes will NOT appear on the device.*
3.  **Compile & Upload**:
    ```powershell
    .\upload_ota.ps1
    ```

### Best Practices
*   **Single File**: Keep everything (CSS, JS, HTML) in `index.html`. External requests (fonts, scripts) will fail on offline networks.
*   **No Frameworks**: Use Vanilla JS. React/Vue are too heavy for the 4MB flash / 300KB RAM constraints if not carefully managed.
*   **Polling vs Sockets**: Prefer polling `/api/status` (2s interval) over independent requests. The ESP32 struggles with concurrent TCP connections.

## Troubleshooting
*   **ReferenceError in Console**: You likely deleted a core function (e.g., `runForceSimulation`) while refactoring. Use `git restore` and apply changes incrementally.
*   **Changes not showing**: You forgot to run `pack_web.py` before uploading.

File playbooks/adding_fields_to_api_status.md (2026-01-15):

# Playbook: Adding Fields to the /api/status Endpoint

*Status: Stable*

## Objective
The `/api/status` endpoint is the heartbeat of the All Seeing Eye. It is polled frequently by the WebUI and other agents to understand the state of the device. This playbook details how to safely add new information to this endpoint while maintaining performance and stability.

## Architecture Context
To minimize overhead on the single-threaded ESP32 web server, the `/api/status` response is **cached in memory**. Be aware that memory is limited and only put essential, fast-to-retrieve data here.
*   **Source File**: `firmware/AllSeeingEye/src/WebServer.cpp`
*   **Method**: `WebServerManager::getCachedStatus()`
*   **Library**: `ArduinoJson`

## Prerequisites
*   The data you want to expose must be accessible from a global context (e.g., Singleton `instance()`, static variable, or hardware read).
*   Avoid blocking operations (e.g., long I/O, heavy computation) inside the status generation logic.
*   Any new or modified API handlers must log request receipt and error conditions via `Logger::instance()`.

## Step-by-Step Instructions

### 1. Identify the Data Source
Determine where the data "lives". It should ideally be available via a simple getter method.
*   *Correct*: `HAL::instance().getBatteryVoltage()` (Fast, memory read)
*   *Incorrect*: `HAL::instance().readBatteryVoltageAndWait()` (Slow, blocking)

### 2. Modify `WebServer.cpp`
Open `firmware/AllSeeingEye/src/WebServer.cpp` and locate the `WebServerManager::getCachedStatus()` function.

Add your new field to the `JsonDocument`.

#### For Simple Values (Numbers, Strings, Booleans):
```cpp
// ... existing code ...
doc["plugin"] = PluginManager::instance().getActivePluginName();

// [NEW] Adding Battery Level
doc["voltage"] = HAL::instance().getBatteryVoltage();
```

#### For Nested Objects:
```cpp
// ... existing code ...
// Create the object container
JsonObject network = doc.createNestedObject("network");

// Add fields to the nested object
network["ssid"] = Config::instance().getSSID();
network["rssi"] = WiFi.RSSI();
```

### 3. Handling Complex/Large Data (Delegation Pattern)
If you are adding a list or complex structure maintaing by another module (like Peers or Logs), do **not** write the iteration logic inside `WebServer.cpp`. Instead, delegate it.

**Pattern:**
1.  **In WebServer.cpp**: Create the array and pass it to the manager.
    ```cpp
    JsonArray sensors = doc.createNestedArray("sensors");
    SensorManager::instance().populateSensorData(sensors);
    ```

2.  **In the Manager Class (Header)**:
    ```cpp
    // SensorManager.h
    void populateSensorData(JsonArray& arr);
    ```

3.  **In the Manager Class (Source)**:
    ```cpp
    // SensorManager.cpp
    void SensorManager::populateSensorData(JsonArray& arr) {
        for (auto& s : _sensors) {
            JsonObject obj = arr.createNestedObject();
            obj["id"] = s.id;
            obj["value"] = s.value;
        }
    }
    ```

### 4. Update Documentation
**CRITICAL**: You must document the new field in `/api/README.md`.

1.  Locate the **System Status** section in `/api/README.md`.
2.  Update the "Response" JSON example to include your new field.
3.  Add a description of the field if its meaning is not obvious.

### 5. Verification
1.  **Compile**: `arduino-cli compile ...`
2.  **Flash**: `upload_ota.ps1` or serial.
3.  **Check**:
    *   Command Line: `curl http://<device_ip>/api/status`
    *   Browser: Go to `http://<device_ip>/api/status`
    *   Verify the new field appears and has the correct value.

## Performance considerations
*   **JSON Size**: The `JsonDocument` has a fixed memory allocation. If you add too much data, `ArduinoJson` may run out of memory and fields will be missing silently. Monitor `doc.overflowed()` if you are adding large arrays.
*   **Cache Duration**: The cache is valid for a short time (e.g., 500ms - 1000ms). Ensure your data doesn't need to be fresher than that.

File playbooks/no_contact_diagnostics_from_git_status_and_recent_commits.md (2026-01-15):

# Playbook: No-Contact Diagnostics from Git Status and Recent Commits

*Status: Draft*

## Objective
Diagnose likely causes of a problem using only `git status`, diffs, and recent commit history, without modifying any files.

## Prerequisites
*   Git installed and available in PowerShell.
*   Local repository access.
*   Read-only intent: no file edits, no restores, no checkouts.

## Step-by-Step Instructions
1.  **Snapshot Working Tree State**
    *   Command:
        ```powershell
        git status -sb
        ```
    *   Expected output: shows current branch and a list of modified/untracked files.
    *   If it fails: confirm you are in the repo root, then retry.

2.  **Summarize Local Changes**
    *   Commands:
        ```powershell
        git diff --stat
        git diff
        ```
    *   Expected output: a per-file change summary and full diffs for uncommitted changes.
    *   If output is too large: narrow to a file or folder:
        ```powershell
        git diff -- firmware/web/index.html
        ```

3.  **Check Recent Commits (If Working Tree Is Clean or Ambiguous)**
    *   Commands:
        ```powershell
        git log -n 5 --oneline
        git show -1 --stat
        ```
    *   Expected output: recent commits with file lists.
    *   If you need a specific file change:
        ```powershell
        git show -1 -- firmware/web/index.html
        ```

4.  **Correlate Errors with Diffs**
    *   Compare reported error locations (e.g., JS `SyntaxError`) with diffs in `firmware/web/index.html` or embedded UI sources.
    *   Pay special attention to:
        -   Unclosed tags or mismatched braces.
        -   Stray commas, duplicated fragments, or partially inserted handlers.
        -   Auto-generated files (e.g., `AllSeeingEye/src/WebStatic.h`) that might reflect stale or broken HTML/JS.

5.  **Record a Read-Only Diagnosis**
    *   Provide a concise summary of:
        -   Files changed.
        -   The exact diff region likely causing the issue.
        -   Whether the change is local (uncommitted) or comes from a recent commit.

## Verification
A successful diagnostic report includes:
*   The `git status -sb` output (or a paraphrase).
*   The specific file(s) implicated.
*   A clear explanation of why the error maps to the diff.

## Notes
*   This playbook is intentionally read-only and does not authorize edits.
*   If a fix is needed, create or reference a separate playbook for patching.

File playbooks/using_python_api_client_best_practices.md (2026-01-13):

# Playbook: Using Python API Client Best Practices

*Status: Draft*

## Objective
To ensure that all Python scripts interacting with the cluster are robust, handle network flakes gracefully, and respect the API standards.

## Best Practices

1.  **Use the `EyeClient` Class**
    *   Do not use `requests.get()` directly in script logic.
    *   Use the wrapper class in `api/client.py` (once implemented) which handles:
        *   Base URL formatting.
        *   JSON parsing.
        *   Exception handling.

2.  **Handle mDNS Latency**
    *   Resolving `.local` domains can take 1-2 seconds.
    *   **Tip**: If performing a high-frequency loop, verify the IP once and cache it, rather than resolving `hostname.local` on every request.

3.  **Respect Timeouts**
    *   ESP32 is single-threaded (mostly). If it's busy, it might delay.
    *   Set `timeout=5` (seconds) on requests.
    *   Catch `requests.exceptions.ConnectTimeout`.

4.  **Data Typing**
    *   The API returns strings for most values to be safe.
    *   Always cast `int(rssi)` before math.

5.  **Handling Errors Gracefully**
    *   **Verbose Logging**: If a request fails, print the full response body. The firmware is designed to return "Self-Correcting" error messages containing valid usage examples.
    *   **Retries**: Implement exponential backoff for network timeouts, but **fail fast** on HTTP 400 (Bad Request) unless the error message suggests a specific fix.
    *   **Validation**: Validate payloads against known schemas in the Python client *before* sending them to the wire.

## Example Pattern

```python
from client import EyeClient

def poll_node(hostname):
    eye = EyeClient(hostname)
    try:
        status = eye.get_status()
        print(f"{hostname} is doing {status['task']}")
    except Exception as e:
        print(f"Failed to reach {hostname}: {e}")
```

## Verification
*   Script runs without crashing when a node is unplugged.
*   Script handles invalid JSON gracefully.

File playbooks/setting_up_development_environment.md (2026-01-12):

# Playbook: Setting Up Development Environment

*Status: Stable*

## Objective
This playbook allows a new developer or agent to set up the local machine for full contribution to the All Seeing Eye project.

## Prerequisites
*   Windows 10/11 (Project scripts are PowerShell-optimized).

## Step-by-Step Instructions

1.  **Install Arduino Environment**
    *   **Arduino IDE 2.x**: Install for the GUI and Drivers.
    *   **Arduino CLI**: Download `arduino-cli.exe`.
        *   *Config*: Currently, the scripts look for `arduino-cli` in a specific path in `AppData`. You may need to edit `upload_ota.ps1` `$CliPath` if yours is different.
    *   **ESP32 Core**: Install `esp32` by Espressif Systems via Board Manager (Version 3.3.3 recommended).

2.  **Install Python Dependencies**
    *   **Command**: `pip install requests zeroconf`
    *   These are used for the desktop Client and Cluster auditing.

3.  **Install OpenSCAD (Optional)**
    *   Required only if editing 3D models.

4.  **Configure Known Hosts**
    *   **File**: `firmware/known_hosts.txt`.
    *   **Action**: Create this file if it doesn't exist. Add the hostnames (e.g., `allseeingeye-123456`) or IPs of your local nodes, one per line.

5.  **Test Deployment Script**
    *   **Command**: `cd firmware; .\upload_ota.ps1`
    *   **Expected**: Code compiles. If no nodes are online, "Offline" is expected, but "Compilation Failed" is a failure.

## Verification
*   `arduino-cli version` returns a version.
*   `python --version` returns 3.x.
*   `upload_ota.ps1` successfully compiles the firmware.

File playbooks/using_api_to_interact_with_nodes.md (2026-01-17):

# Playbook: Using the API to Interact with Nodes

*Status: Active*

## Objective
Provide a consistent, safe procedure for agents and users to interact with nodes via the Python API and validate firmware versions and endpoint availability without introducing configuration drift.

## Preconditions
- Python environment with dependencies installed from `api/requirements.txt`.
- Access to the local network hosting the nodes.

## 1. Validate Firmware Version (Build Hash)

**Goal**: Confirm that a node is running the same firmware build as the repository.

1.  **Read the expected build hash from the repo**:
    *   File: `firmware/AllSeeingEye/src/BuildVersion.h`
    *   Field: `BUILD_ID`

2.  **Fetch the node’s reported build hash**:
    *   Endpoint: `GET /api/status`
    *   Field: `build_id`

3.  **Compare**:
    *   If `status.build_id != BUILD_ID`, the node is running a different firmware build.
    *   Do not assume missing fields are a bug until versions are aligned.

**Python Example**:
```python
from client import EyeClient

client = EyeClient("192.168.1.111")
status = client.get("/api/status")
print(status["data"]["build_id"])
```

## 2. Discover and Select a Target Node

**Rule**: Always target nodes by **hostname**, or **description** (quoted if spaces). (IP Addresses change frequently, and future versions will support connections across meshtastic where ip addresses don't exist.)

1.  **List known hosts** (auto-discovers if none exist):
    ```bash
    python api/cli.py --list
    ```

2.  **Target by hostname**:
    ```bash
    python api/cli.py --host "allseeingeye-xyzabc" get /api/status
    ```

3.  **Target by description**:
    ```bash
    python api/cli.py --host "garage" get /api/status
    ```

## 3. Endpoint Inventory

**Authoritative Reference**:  
The complete list of API endpoints, methods, and payloads is maintained in **[`api/README.md`](../api/README.md)**. Please refer to that document for the full protocol specification.

The examples below demonstrate the *syntax* for interacting with these endpoints using the Python client.

**CLI Parity Rule**: Every endpoint in `api/README.md` must be callable from the CLI for debugging and verification. If a dedicated command does not exist, use the generic `get`/`post` form and document the example.

## 4. Python API Usage Patterns

**General GET**:
```python
from client import EyeClient

client = EyeClient("192.168.1.111")
status = client.get("/api/status")
print(status)
```

**POST with payload**:
```python
from client import EyeClient

client = EyeClient("192.168.1.111")
response = client.post("/api/config", {
    "description": "lab node",
    "timezone": "America/Los_Angeles"
})
print(response)
```

**Cluster Task Deploy**:
```bash
python api/cli.py post /api/cluster/deploy '{"task":"spectrum/scan", "params": {"start": 902.0, "stop": 928.0}}'
```

**Cluster Task Start**:
```bash
python api/cli.py post /api/cluster/start '{}'
```

**Cluster Report**:
```bash
python api/cli.py get /api/report
```

**LED Set (GET with query params)**:
```python
from client import EyeClient

client = EyeClient("192.168.1.111")
response = client.get("/api/led?r=255&g=0&b=0")
print(response)
```

**Ping a peer**:
```python
from client import EyeClient

client = EyeClient("192.168.1.111")
response = client.get("/api/ping?target=192.168.1.106")
print(response)
```

## 5. Safety and Consistency Checks

- **Version Mismatch**: Treat missing fields as firmware version mismatch first.
- **No TX/Passive Only**: Do not add any RF transmit logic; firmware is passive-only by policy.
- **Always Log**: When changing config or rebooting, capture logs (`/api/logs`) before and after.

## 6. Verification Checklist

1.  `GET /api/status` returns `build_id` and expected fields.
2.  `GET /api/config` includes required fields (e.g., `timezone`).
3.  `GET /api/peers` returns expected peers for the node.
4.  `POST /api/config` returns success and changes appear in subsequent GET.
5.  `GET /api/logs/head` contains startup events if troubleshooting boot issues.

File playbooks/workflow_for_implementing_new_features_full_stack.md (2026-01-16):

# Playbook: Workflow for Implementing New Features (Full Stack)

*Status: Stable*

## Objective
This playbook defines the "Full Stack" development process for adding a new capability to the All Seeing Eye. It ensures that no feature exists in the firmware without being accessible via the API and documented for agents.

## Prerequisites
*   Development Environment set up (VS Code, Arduino CLI, Python).
*   Understanding of the `Kernel` -> `Plugin` architecture.

## Step-by-Step Instructions

1.  **Define the Feature Contract**
    *   **Action**: Decide on the API endpoint first.
    *   *Example*: `POST /api/led/blink` -> `{"duration": 1000}`.
    *   **Document it**: Add to `api/README.md` *immediately*.

2.  **Implement Firmware Logic (C++)**
    *   **File**: `firmware/AllSeeingEye/src/Kernel.cpp` (or a specific Plugin).
    *   **Action**: Add the handler in `setupWebServer()`.
    *   *Code*: `server.on("/api/led/blink", HTTP_POST, ...)`
    *   **Logging Requirement**: Every API handler must log request receipt and any errors, plus all significant state changes and success paths (so the feature is observable in `/api/logs` and `/api/status`).
    *   **Test**: Compile and deploy to one node. Verify with `curl` or Postman.

3.  **Implement Python Client Wrapper**
    *   **File**: `api/client.py`.
    *   **Action**: Add a method to the `EyeClient` class.
    *   *Code*:
        ```python
        def blink_led(self, duration_ms=1000):
            return self._post("/api/led/blink", {"duration": duration_ms})
        ```

4.  **Expose in the CLI (Required)**
    *   **File**: `api/cli.py`.
    *   **Action**: Every API endpoint must be callable from the CLI for debugging and verification.
    *   **Rule**: If the CLI already supports generic `get`/`post`, add a documented CLI example for the new endpoint.
    *   **Why**: Field operations rely on CLI parity when WebUI is unavailable.

5.  **Update Agent Playbooks (If needed)**
    *   If this feature changes how we deploy or troubleshoot (e.g., a new "Safe Mode"), create or update the relevant playbook in `playbooks/`.

6.  **Final Verification**
    *   Run a Python script calling the new method.
    *   Run the CLI command for the same endpoint.
    *   Observe the physical device response.
    *   Check `AGENTS.md` and `README.md` to ensure they are up to date.

## Verification
*   Current Code matching Documentation.
*   Feature works via Desktop API.
*   Feature works via CLI (debug parity).
*   Feature works via Web UI (if applicable).

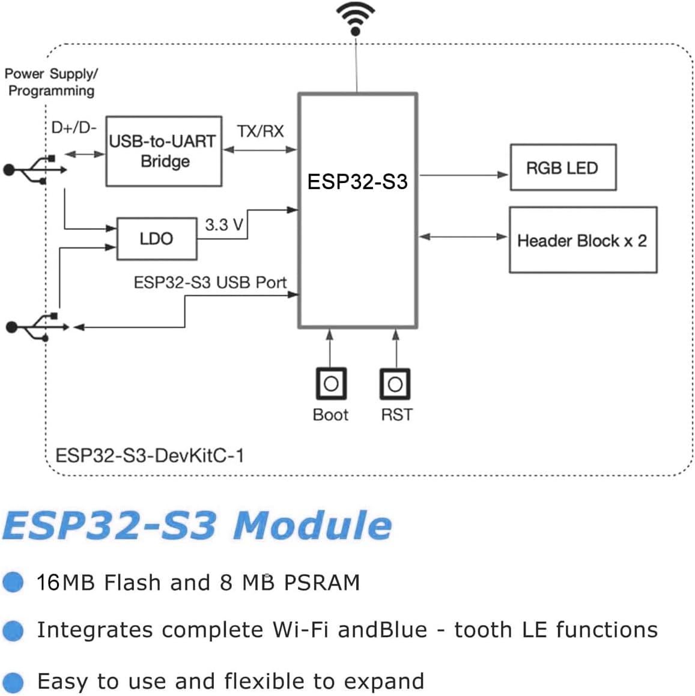
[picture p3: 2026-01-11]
3d models/design/esp/61R3kyW2NdL._AC_SL1200_.jpg

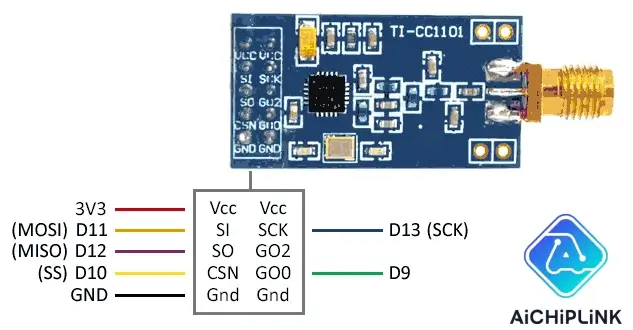
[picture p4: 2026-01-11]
3d models/design/cc1101/arduino-cc1101-conexion.webp

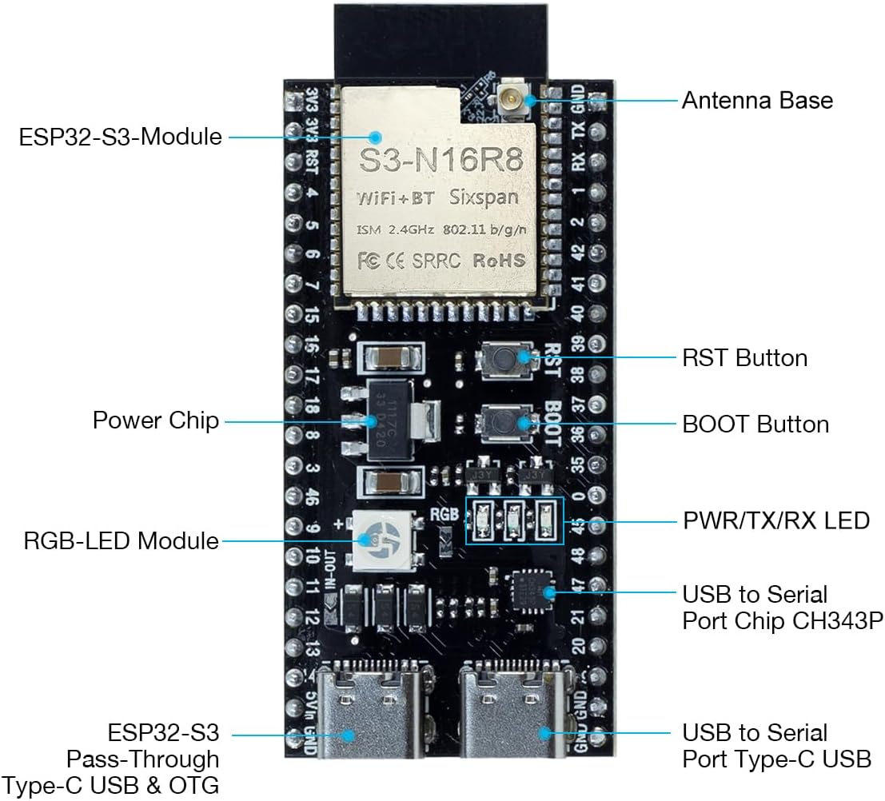
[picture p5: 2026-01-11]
3d models/design/esp/615G1YHuZWL._AC_SL1200_.jpg

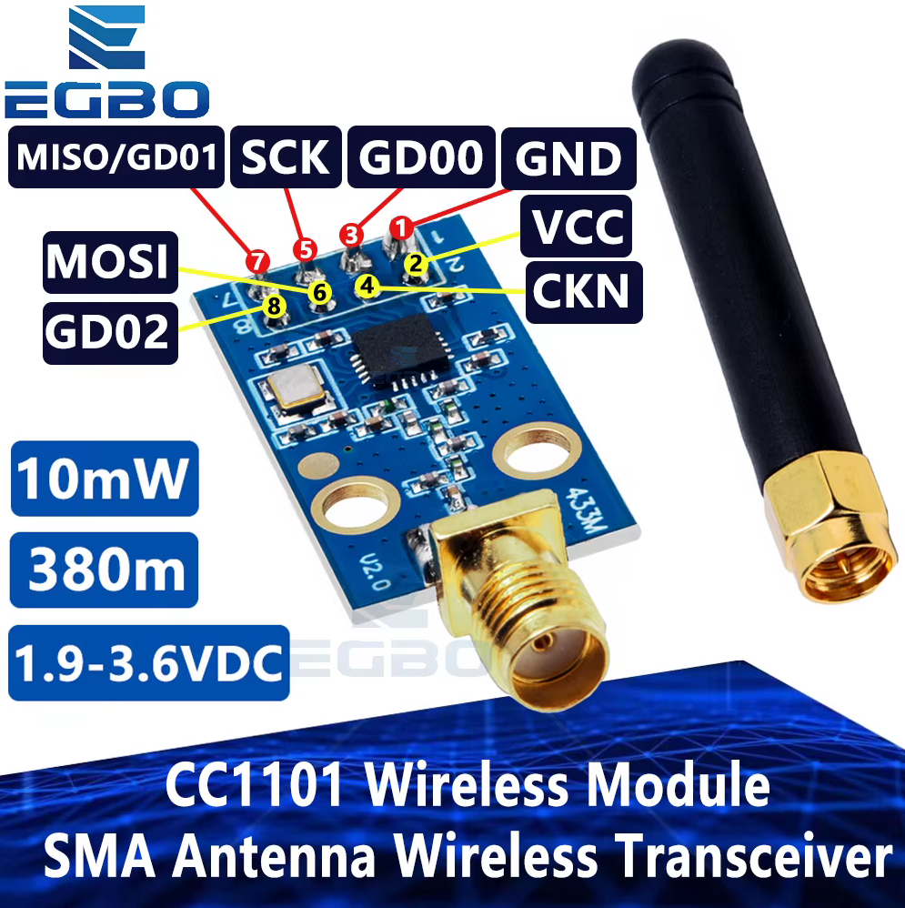
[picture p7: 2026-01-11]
3d models/design/cc1101/diagram.PNG

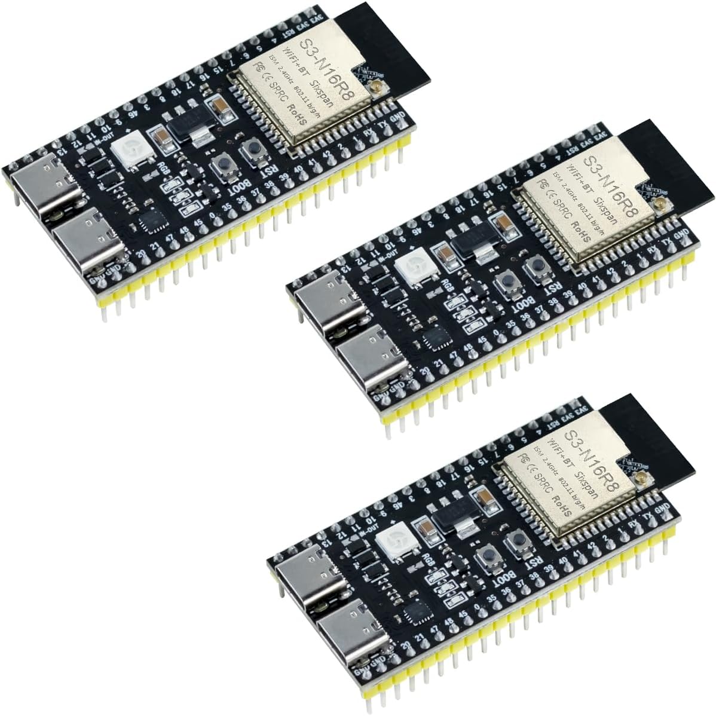
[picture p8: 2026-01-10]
3d models/design/esp/71GKGndDkWL._AC_SL1200_.jpg

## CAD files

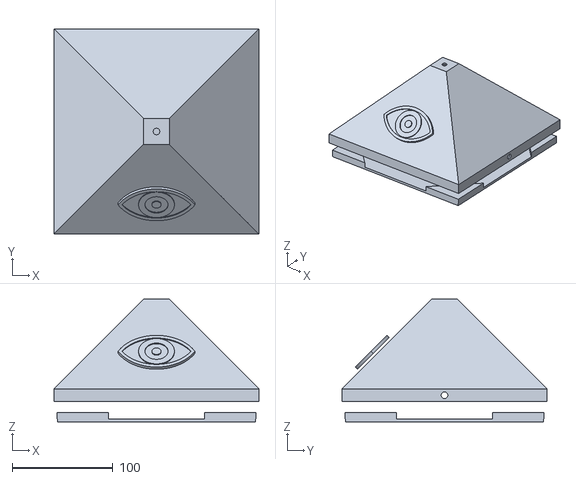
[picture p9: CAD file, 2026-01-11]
3d models/build/assembly.1.0.stl
203.2 x 203.2 x 121.6

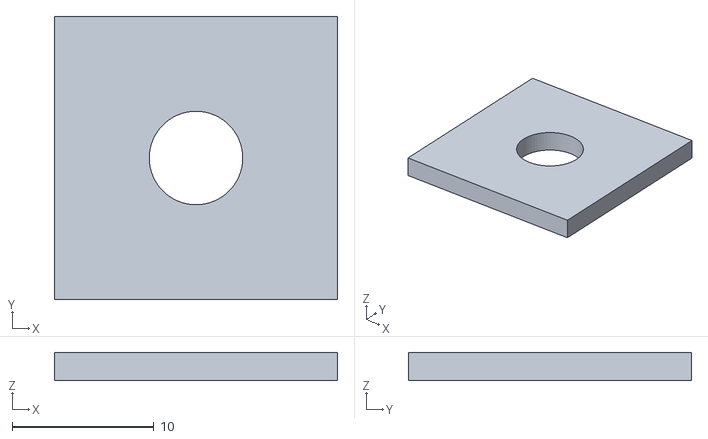
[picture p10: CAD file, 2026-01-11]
3d models/build/sma-test-2mm.stl
20.0 x 20.0 x 2.00

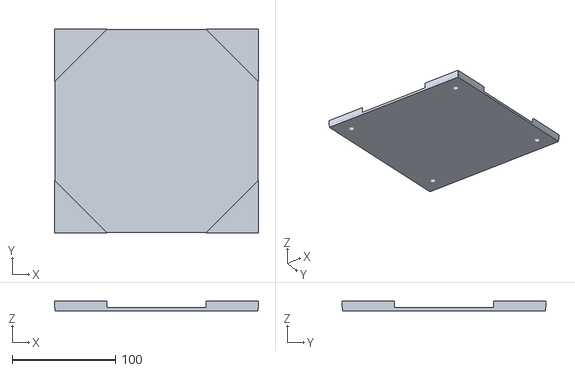
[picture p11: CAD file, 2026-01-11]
3d models/build/base-plate.1.0.stl
197.2 x 197.2 x 9.35

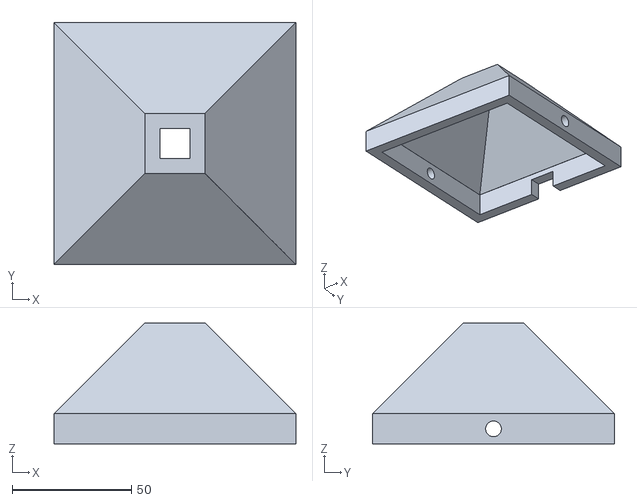
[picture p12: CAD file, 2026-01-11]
3d models/build/all-seeing-eye.1.0.stl
101.6 x 101.6 x 50.8

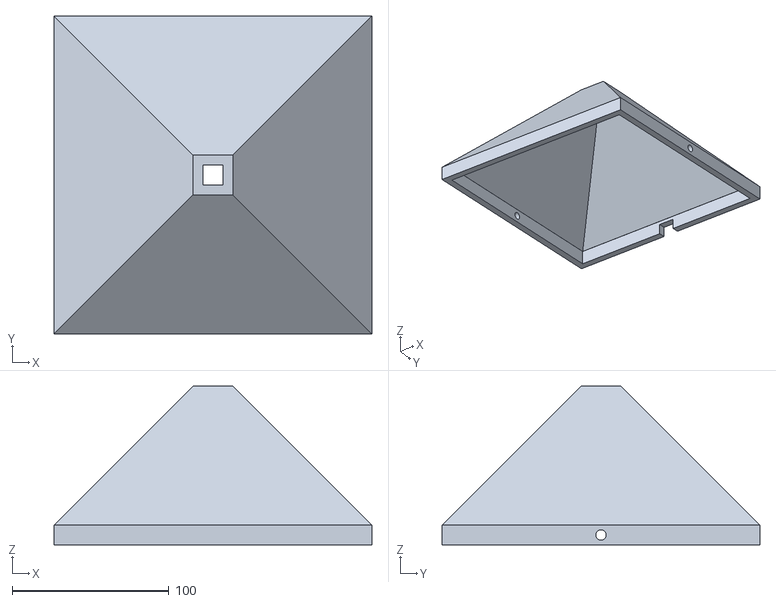
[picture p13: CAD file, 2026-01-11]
3d models/build/all-seeing-eye.1.1.stl
203.2 x 203.2 x 101.6

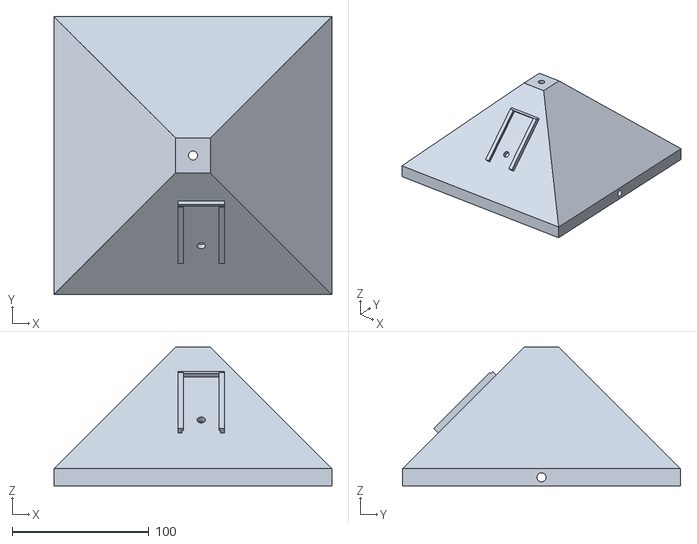
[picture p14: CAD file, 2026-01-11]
3d models/build/all-seeing-eye.1.4.stl
203.2 x 203.2 x 101.6

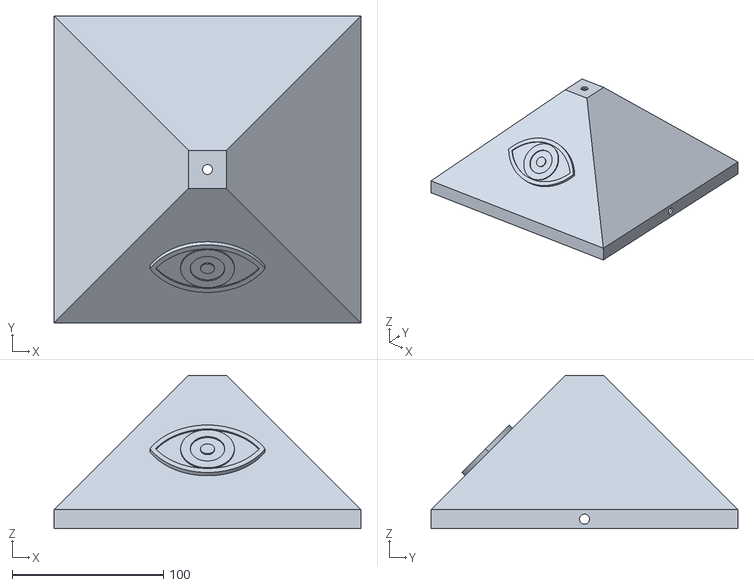
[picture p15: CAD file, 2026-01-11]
3d models/build/combined-1.0.stl
203.2 x 203.2 x 101.6

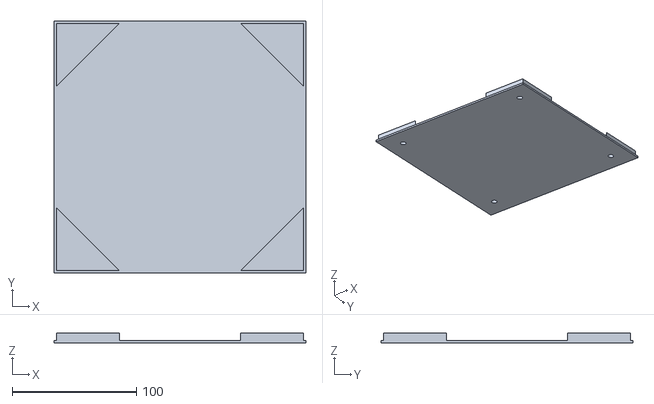
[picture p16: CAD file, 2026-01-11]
3d models/build/base-plate.1.1.stl
203.2 x 203.2 x 8.35

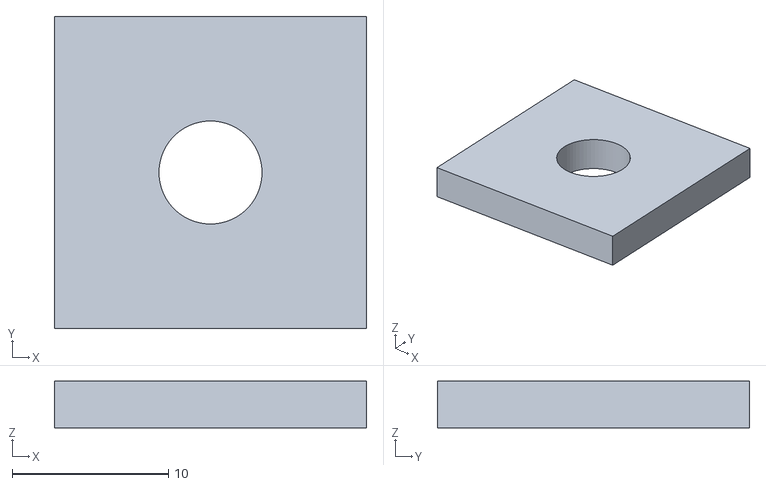
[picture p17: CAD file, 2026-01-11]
3d models/build/sma-test-3mm.stl
20.0 x 20.0 x 3.00

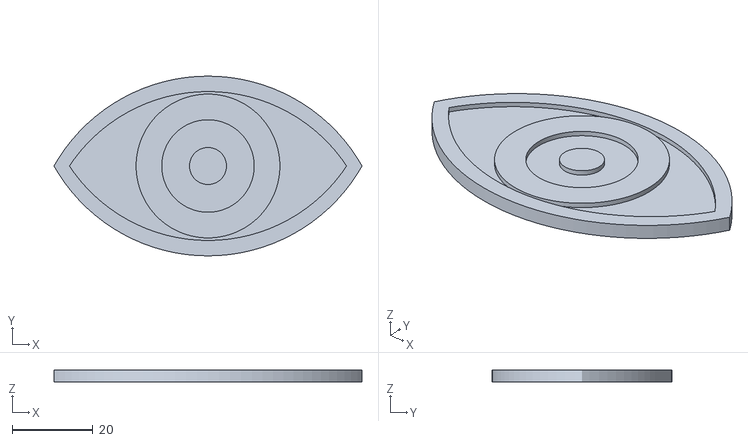
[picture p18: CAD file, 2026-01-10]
3d models/build/eye-symbol.1.0.stl
76.2 x 44.5 x 3.05

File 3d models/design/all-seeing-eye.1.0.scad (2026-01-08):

// All-Seeing Eye Enclosure Design
// Unit: mm (Converted from freedom units)

/* [Global Dimensions] */
INCH = 25.4;

// Base Specifications
base_width = 4.0 * INCH;
base_height = 0.5 * INCH;
wall_thickness = 0.25 * INCH;

// Pyramid Specifications
// Slope is 45 degrees.
// For a 45 degree slope, the change in height equals the change in radius (distance from center).
// Height to Apex = (base_width / 2) * tan(45) = base_width / 2
slope_angle = 45; 

// Top flat area for SMA connector
top_width = 1.0 * INCH; 

// Calculate pyramid height based on slope and top width
// The horizontal run from base edge to top edge is: (base_width - top_width) / 2
// height = run * tan(angle). Since angle is 45, tan is 1.
pyramid_height = (base_width - top_width) / 2;

// Connector Dimensions
sma_hole_diameter = 0.26 * INCH; // ~6.6mm, purely clearance for SMA thread
usb_cutout_width = 0.6 * INCH;
usb_cutout_height = 0.3 * INCH; // Height of the actual hole
usb_cable_clearance = 0.5 * INCH; // Width of slot at bottom

/* [Rendering resolution] */
$fn = 60;

module main() {
    difference() {
        // 1. Positive Volume (The Shell)
        union() {
            // A. Base Prism
            translate([0, 0, base_height/2])
                cube([base_width, base_width, base_height], center=true);
            
            // B. Pyramid Frustum
            // Positioned on top of the base
            translate([0, 0, base_height])
                pyramid_frustum(base_width, top_width, pyramid_height);
        }

        // 2. Negative Volume (The Hollow)
        union() {
            // A. Hollow Base
            // Subtract thickness from X and Y, but allow Z to cut through to pyramid
            translate([0, 0, base_height/2])
                cube([base_width - 2*wall_thickness, base_width - 2*wall_thickness, base_height + 0.1], center=true);
            
            // B. Hollow Pyramid
            // To maintain roughly constant wall thickness perpendicular to a 45 deg slope is tricky with simple scaling.
            // Simple approach: Subtract inner pyramid starting at same height, but with smaller base.
            // Inner base width = Outer Width - 2 * wall_thickness
            // We want the inner void to match up with the base void.
            inner_base_width = base_width - 2*wall_thickness;
            inner_top_width = max(0, top_width - 2*wall_thickness); // Ensure it doesn't invert
            
            // The height of the inner pyramid needs to be calculated or offset carefully.
            // Since it's 45 degrees, the inner ceiling is lower by 'wall_thickness'.
            translate([0, 0, base_height])
                 pyramid_frustum(inner_base_width, inner_top_width, pyramid_height);
        }

        // 3. Cutouts / Holes
        
        // A. Top SMA Connector (Apex)
        translate([0, 0, base_height + pyramid_height - 1]) // Start slightly below top
            cylinder(h = wall_thickness + 2, d = sma_hole_diameter, center = false);

        // B. Left Face SMA (WiFi) - Looking from Front
        // Front is -Y (standard convention often, but let's define Front).
        // Let's assume:
        // +Y = Back (Rear)
        // -Y = Front
        // -X = Left
        // +X = Right
        
        // Left Face (-X)
        translate([-base_width/2 + wall_thickness/2, 0, base_height/2])
            rotate([0, 90, 0])
            cylinder(h = wall_thickness + 2, d = sma_hole_diameter, center = true);

        // C. Right Face SMA (Meshtastic) (+X)
        translate([base_width/2 - wall_thickness/2, 0, base_height/2])
            rotate([0, 90, 0])
            cylinder(h = wall_thickness + 2, d = sma_hole_diameter, center = true);

        // D. Rear Face USB (+Y)
        // "Hole reaching to the bottom of the base"
        translate([0, base_width/2 - wall_thickness/2, 0]) // At bottom Z=0
            cube([usb_cutout_width, wall_thickness + 2, base_height*1.5], center = true);
            
    }
}

// Module to create a centered 4-sided pyramid frustum
module pyramid_frustum(base_w, top_w, h) {
    // OpenSCAD's cylinder with $fn=4 creates a square rotated by 45 degrees.
    // To align it with axes, we rotate it by 45 degrees.
    // circumradius = side / sqrt(2) * 2? No.
    // side = r * sqrt(2). r = side / sqrt(2).
    
    r_base = (base_w / 2) * sqrt(2);
    r_top = (top_w / 2) * sqrt(2);
    
    rotate([0, 0, 45])
        cylinder(h=h, r1=r_base, r2=r_top, $fn=4);
}

main();

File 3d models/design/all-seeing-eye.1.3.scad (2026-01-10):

// All-Seeing Eye Enclosure Design
// Unit: mm (Converted from freedom units)

/* [Global Dimensions] */
INCH = 25.4;

// Base Specifications
// 8.0 inches (203.2 mm) outer width
base_width = 8.0 * INCH;
base_height = 0.5 * INCH;
wall_thickness = 0.25 * INCH;

// Pyramid Specifications
// Slope is 45 degrees.
slope_angle = 45; 

// Top flat area for SMA connector
top_width = 1.0 * INCH; 

// Calculate pyramid height based on slope and top width
// height = run * tan(angle). Since angle is 45, tan is 1.
pyramid_height = (base_width - top_width) / 2;

/* [Interface Dimensions] */
// Connector Dimensions
sma_hole_diameter = 0.26 * INCH;
usb_cutout_width = 0.6 * INCH;
usb_cutout_height = 0.3 * INCH;
usb_cable_clearance = 0.5 * INCH;

// ESP32-S3 Board Dimensions & Mounting
// PCB Physical Dimensions
pcb_width = 28.0;  // Measured: 2.8cm
pcb_length = 58.0; // Measured: 5.8cm
pcb_thickness = 1.6; // Standard PCB thickness (approx)

// LED Position Logic
// "Left side of board to right side of LED is 11mm"
// LED is 6mm wide.
// Center X = Right Edge (11) - Half Width (3) = 8mm from left edge?
// Re-read carefuly: "left side of board to right side of led is 11mm"
// So LED Right Edge is at X=11.
// LED Left Edge is at X=11-6 = 5.
// LED Center X = 5 + 3 = 8mm.
// Confirm centering: If PCB is 28mm wide... Center is 14mm.
// 8mm is definitely not centered on PCB. It's offset to left.

// "Top of LED to bottom of USB is 21mm"
// LED is 6mm tall.
// "Bottom of USB" = Bottom edge of PCB (Datum Y=0)
// "Top of LED" is at Y=21.
// LED Bottom Edge is at Y=21-6 = 15.
// LED Center Y = 15 + 3 = 18mm from bottom edge.

led_center_x = 8.0;  // From left edge
led_center_y = 18.0; // From bottom edge (USB end)
led_size = 6.0;

// Mounting Config
// The board should be mounted inside the pyramid.
// We need to place it such that the LED Center aligns with a new hole on the front face.
// Front Face is -Y face.
// The hole should be centered horizontally on the face.
// But the LED is NOT centered on the PCB (8mm vs 14mm center).
// So the PCB must be mounted OFFSET from the pyramid center line by (14 - 8) = 6mm.

/* [Rendering resolution] */
$fn = 60;

module main() {
    difference() {
        // 1. Positive Volume (The Shell)
        union() {
            // A. Base Prism
            translate([0, 0, base_height/2])
                cube([base_width, base_width, base_height], center=true);
            
            // B. Pyramid Frustum
            translate([0, 0, base_height])
                pyramid_frustum(base_width, top_width, pyramid_height);
        }

        // 2. Negative Volume (The Hollow)
        union() {
            // A. Hollow Base
            translate([0, 0, base_height/2])
                cube([base_width - 2*wall_thickness, base_width - 2*wall_thickness, base_height + 0.1], center=true);
            
            // B. Hollow Pyramid
            inner_height = pyramid_height - wall_thickness;
            inner_base_width = base_width - 2*wall_thickness;
            inner_top_width = top_width;

            translate([0, 0, base_height])
                 pyramid_frustum(inner_base_width, inner_top_width, inner_height);
        }

        // 3. Cutouts / Holes
        
        // A. Top SMA Connector (Apex)
        // Must penetrate the roof thickness.
        translate([0, 0, base_height + pyramid_height - wall_thickness - 1]) 
            cylinder(h = wall_thickness + 2, d = sma_hole_diameter, center = false);

        // B. Left Face SMA (WiFi)
        translate([-base_width/2 + wall_thickness/2, 0, base_height/2])
            rotate([0, 90, 0])
            cylinder(h = wall_thickness + 2, d = sma_hole_diameter, center = true);

        // C. Right Face SMA (Meshtastic)
        translate([base_width/2 - wall_thickness/2, 0, base_height/2])
            rotate([0, 90, 0])
            cylinder(h = wall_thickness + 2, d = sma_hole_diameter, center = true);

        // D. Rear Face USB
        translate([0, base_width/2 - wall_thickness/2, 0])
            cube([usb_cutout_width, wall_thickness + 2, base_height*1.5], center = true);
            
        // E. Front Face Eye Hole (NEW)
        // Located on the -Y face.
        // Needs to clearly show the LED.
        // Let's place it at a height reasonable for the board mounting.
        // If board is mounted vertically, Y is Up. IF mounted horizontally, Z is up.
        // We haven't defined mounting orientation yet, but user wants hole on Face.
        // Let's create a placeholder hole half-way up the face for now to show intent.
        
        eye_hole_y_offset = -base_width/4; // Rough position on -Y face
        eye_hole_z_height = base_height + pyramid_height/3; 
        
        // Project a cylinder perpendicular to the 45 deg face
        translate([0, -base_width/4, eye_hole_z_height]) 
            rotate([45, 0, 0]) // Angle to match face normal roughly (check math later)
            cylinder(h = wall_thickness * 4, d = led_size * 1.5, center = true);
    }
}

// Module to create a centered 4-sided pyramid frustum
module pyramid_frustum(base_w, top_w, h) {
    r_base = (base_w / 2) * sqrt(2);
    r_top = (top_w / 2) * sqrt(2);
    
    rotate([0, 0, 45])
        cylinder(h=h, r1=r_base, r2=r_top, $fn=4);
}

main();

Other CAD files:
version 1.0.dwg
3d models/build/all-seeing-eye.1.2.stl
3d models/build/all-seeing-eye.1.5.stl
3d models/build/all-seeing-eye.1.3.stl
3d models/build/all-seeing-eye.1.6.stl
3d models/build/combined-1.1.stl
3d models/design/all-seeing-eye.1.1.scad
3d models/design/all-seeing-eye.1.2.scad
3d models/design/all-seeing-eye.1.4.scad
3d models/design/all-seeing-eye.1.5.scad
3d models/design/all-seeing-eye.1.6.scad
3d models/design/assembly.1.0.scad
3d models/design/base-plate.1.0.scad
3d models/design/base-plate.1.1.scad
3d models/design/combined-1.0.scad
3d models/design/combined-1.1.scad
3d models/design/eye-symbol.1.0.scad
3d models/design/sma-test-2mm.scad
3d models/design/sma-test-3mm.scad

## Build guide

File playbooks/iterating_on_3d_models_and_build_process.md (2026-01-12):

# Playbook: Iterating on 3D Models and Build Process

*Status: Stable*

## Objective
This playbook explains how to modify the physical design of the Eye, rebuild the STL files using OpenSCAD, and update the repository artifacts.

## Prerequisites
*   OpenSCAD installed (and added to PATH, or standard install location).
*   `3d models/` directory structure.

## Step-by-Step Instructions

1.  **Modify Source Files (Versioning)**
    *   **Location**: `3d models/design/*.scad`.
    *   **Rule**: **Do not overwrite existing files**. Always save your changes as a new minor revision.
        *   *Example*: Copy `all-seeing-eye.1.6.scad` to `all-seeing-eye.1.7.scad` before making changes.
    *   **Action**: Edit the new SCAD file. Use `assembly.1.0.scad` (updated to point to your new file) to visualize how parts fit together.

2.  **Generate STLs (Build)**
    *   **Context**: Open terminal in `3d models/`.
    *   **Command**: `.\build.bat`
    *   **Process**: The script finds OpenSCAD and compiles every `.scad` file in `design/` to an `.stl` file in `build/`.

3.  **Inspect Artifacts**
    *   **Location**: `3d models/build/`.
    *   **Action**: Open the new STLs in a slicer (Cura/PrusaSlicer) or 3D viewer to check for manifold errors or geometry issues.

4.  **Commit Changes**
    *   Commit both the source (`.scad`) and the binary artifacts (`.stl`). This allows people without OpenSCAD to print immediately.

## Verification
*   Date modified of files in `build/` matches current time.
*   File size of STLs is non-zero.
*   Physical print matches design intent.

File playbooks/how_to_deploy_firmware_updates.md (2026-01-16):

# Playbook: How to Deploy Firmware Updates

*Status: Stable*

## Objective
This playbook describes the process for compiling, packing web assets, and deploying firmware updates to the entire All Seeing Eye fleet using the `upload_ota.ps1` script.

## Prerequisites
*   **Operating System**: Windows (PowerShell 5.1+).
*   **Tools**: Arduino CLI, Python 3 (for packing assets), `espota.exe`.
*   **Network**: Desktop must be on the same local network as the nodes.
*   **Context**: You must be in the `firmware/` directory of the repository.

### CRITICAL AGENT INSTRUCTION: SYNCHRONOUS EXECUTION
**Compiling firmware takes time (30-60 seconds).**
*   **Tool Setting**: You MUST set `isBackground: false` when using `run_in_terminal`.
*   **Blocking**: This setting forces the AI to wait until the `upload_ota.ps1` script exits.
*   **Verification**: Do not proceed until you receive the full text output ending in "All Tasks Completed".
*   If the tool call times out or returns partial output, verify the log file `build/compile.log` before proceeding.

## Step-by-Step Instructions

1.  **Navigate to Firmware Directory**
    *   Command: `cd firmware`
    *   Reason: The script uses `$PSScriptRoot` relative paths, but running it from the root without `cd` can sometimes cause context issues.

2.  **Execute the Deployment Script**
    *   Command: `.\upload_ota.ps1`
    *   *Note*: If you run into Execution Policy errors, use: `PowerShell -ExecutionPolicy Bypass -File .\upload_ota.ps1`

3.  **Monitor the Output**
    *   **Phase 1: Packing Web Assets**: The script runs `pack_web.py`. Ensure it says "[PACK] Done."
    *   **Phase 2: Compiling Firmware**: The script calls `arduino-cli`. This process takes 30-60 seconds.
        *   **Do not continue** until the script prints `All Tasks Completed.`
        *   *If it fails*: The error log is at `build/compile.log`. Read it to diagnose (usually missing libraries or syntax errors).
    *   **Phase 3: Deployment**: The script iterates through `known_hosts.txt`.
        *   **Auto-Retry**: If a node update fails, the script will POST `/api/reboot`, wait briefly, and retry the OTA once before moving to the next node.

4.  **Verify Success**
    *   **Success**: Output shows `Target: [hostname] ... Status: ONLINE ... SUCCESS`.
    *   **Failure**: Output shows `FAILED`. Check `build/upload_[hostname].log` for details.

## Troubleshooting

*   **"Index.html not found"**: You are likely running the script from the repo root. `cd firmware` first.
*   **"Compilation Failed"**: Open `build/compile.log`.
    *   *Symptom*: `fatal error: header.h: No such file`.
    *   *Fix*: Check `libraries/` folder or `arduino-cli` library include paths.
*   **"Offline (Skipping)"**:
    *   Check if the node is powered on.
    *   Check if the hostname is resolvable (`ping [hostname]`).
    *   If mDNS is broken, try using the IP address in `known_hosts.txt` instead of the hostname.

## Verification
1.  Visit `http://[hostname].local` (or IP) in a browser.
2.  Check the "API Status" at `http://[hostname].local/api/status` to confirm the version or build time matches your update.

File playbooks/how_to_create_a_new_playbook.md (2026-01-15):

# Playbook: How to Create a New Agent Playbook

*Status: Stable*

This playbook outlines the standard procedure for an AI Agent to create a new operational playbook for the All Seeing Eye project. Playbooks are essential for standardizing complex tasks, troubleshooting, and development workflows.

## 1. Prerequisites & Context Gathering

**CRITICAL STEP**: Before attempting to write a new playbook, you must establish a complete mental model of the system. Do not skip this.

1.  **Read the Root Documentation**:
    *   `README.md`: Understand the project's physical form, high-level architecture (SDR vs. Eye nodes), and goals.
    *   `AGENTS.md`: Understand the organizational structure, API standards, and the role of agents.
2.  **Read Component Documentation**:
    *   `firmware/README.md`: Understand the C++ implementation, networking logic, and current capabilities.
    *   `api/README.md`: Understand how the desktop client and LLMs interact with the cluster.
3.  **Verify Current State**:
    *   Check `playbooks/` to ensure a similar playbook does not already exist.

## 2. When to Create a Playbook

Create a new playbook when:
*   **Complexity**: A task involves more than 3 distinct steps or spans multiple domains (e.g., Firmware + Python + Documentation).
*   **Repetition**: The user asks for the same multi-step operation frequently.
*   **Troubleshooting**: You successfully solve a difficult error (e.g., "Build failed due to missing library") and want to document the fix for future agents.
*   **Workflow**: A new feature is added that requires a specific deployment or testing sequence.

## 3. Drafting the Playbook

### Filename Convention
*   Use **verbose, descriptive filenames** using snake_case.
*   The filename should be a sentence fragment that answers "What is this for?".
*   *Bad*: `deploy.md`, `fix_error.md`
*   *Good*: `how_to_deploy_firmware_updates.md`, `troubleshooting_offline_nodes.md`

### File Structure
Start with the following template:

```markdown
# Playbook: [Title of the Task]

*Status: [Draft | Stable | Deprecated]*

## Objective
A 1-sentence summary of what this playbook achieves.

## Prerequisites
*   Tools required (e.g., PowerShell, Arduino CLI).
*   Access required (e.g., Local Network, USB Cable).

## Step-by-Step Instructions
1.  **Step Name**: 
    *   Command to run.
    *   Expected output.
    *   What to do if it fails.

## Verification
How to confirm the task was successful.
```

## 4. Writing Guidelines

*   **Be Specific**: Do not say "Run the script." Say "Run `.\firmware\upload_ota.ps1` from the project root."
*   **Anticipate Failure**: If a step is prone to error (like network timeouts), provide a specific remediation sub-step.
*   **Code-First**: Where possible, reference specific scripts in the repo rather than writing long manual terminal commands.
*   **Idempotency**: Playbooks should ideally be repeatable without breaking the system.

## 5. Finalizing

1.  Save the file to `playbooks/`.
2.  (Optional) If this is a major workflow, mention it in `AGENTS.md` under the "Agent Playbooks" section.

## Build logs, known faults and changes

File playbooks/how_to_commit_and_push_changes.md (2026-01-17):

# Playbook: How to Commit and Push Changes

*Status: Draft*

## Objective
Provide a repeatable workflow to summarize staged changes, propose a commit message, and push to `origin` after user approval, without assuming untracked files should be added.

## Prerequisites
*   Git installed and available in PowerShell.
*   Changes staged (`git add ...`).
*   Access to the remote `origin`.

## Step-by-Step Instructions

1.  **Check Repository Status**
    *   Command: `git status -sb`
    *   Expected: Shows staged files under `Changes to be committed`, and any untracked files under `??`.
    *   If nothing staged: run `git add <files>` and re-check.

2.  **Handle Untracked Files (Never Assume They Should Be Added)**
    *   If untracked files exist, list them explicitly and ask the user to choose one of:
        *   **Add to Git Ignore** add untracked files to `.gitignore`, then re-check status.
        *   **Add** specific untracked files to staging, then re-check status.
    *   Do not add new files without explicit user instruction.

3.  **Review Staged Diff with `dump_staged.ps1`**
    *   Command (from repo root): `./dump_staged.ps1 > staged_dump.txt`
    *   Expected: `staged_dump.txt` contains the full staged file contents.
    *   If the script warns “No staged changes found”, return to Step 1.

4.  **Summarize Changes**
    *   Read `staged_dump.txt` and produce:
        *   A concise bullet list of changes since the last commit.
        *   A single-sentence commit message suggestion (imperative mood).

5.  **Request Approval**
    *   Ask the user to approve the summary and commit message.
    *   Confirm how to handle any untracked files (ignore, add specific files, or stop).
    *   Do **not** commit until explicit approval is given.

6.  **Commit After Approval**
    *   Command: `git commit -m "<approved message>"`
    *   Expected: Commit created with the approved message.
    *   If commit fails: re-check staged files and resolve any errors.

7.  **Push to Origin**
    *   Command: `git push origin HEAD`
    *   Expected: Remote updated with the new commit.
    *   If push fails: capture the error output and report it.

## Verification
*   `git log -1 --oneline` shows the new commit.
*   `git status -sb` is clean.
*   `git push origin HEAD` succeeds.

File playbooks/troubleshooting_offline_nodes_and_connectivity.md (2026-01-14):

# Playbook: Troubleshooting Offline Nodes and Connectivity

*Status: Stable*

## Objective
This playbook provides a systematic checklist for **Agents** to diagnose "Offline" or "Unknown" nodes. Since Agents cannot see the physical devices, this workflow combines **direct terminal actions** with **questions for the User**.

## Prerequisites
*   Powershell terminal access.
*   User presence (for physical inspection).

## Step-by-Step Triage

1.  **Phase 1: Agent Active Reconnaissance (Do this first)**
    *   **Goal**: Determine if the node is network-reachable without bothering the user yet.
    *   **Action 1**: Check if the host resolves.
        *   Command: `ping -n 1 [hostname].local`
    *   **Action 2**: Scan IP Table if hostname fails.
        *   Command: `arp -a`
        *   *Analysis*: Search output for Espressif MAC OUI (`48:E7`, `54:32`, etc).
    *   **Action 3 (New)**: Check the **Startup Logs** if the device is responsive but behaving oddly.
        *   Command: `curl http://[hostname].local/api/logs/head`
        *   *Analysis*: Look for "Failed to mount FS", "Radio Init Failed", or "WiFi Reason" codes. This buffer is preserved even if the runtime logs rotate.
    *   **Result**: 
        *   If responding to Ping: Node is Alive (Network Layer OK). Problem is likely Application Layer (Web Server crashed).
        *   If NO response: Node is network-dead. Proceed to Phase 2.

2.  **Phase 2: User Physical Inspection (Ask the User)**
    *   **Goal**: Determine if the node has power or has crashed hard.
    *   **Agent Prompt**: "I cannot reach node `[hostname]`. Please look at the device and tell me:"
        1.  "Is the **Red Power LED** on?" (Power Good)
        2.  "Is the **Blue Status LED** blinking?" (Heartbeat = Kernel Running).
        3.  "Is the **Blue Status LED** solid on or solid off?" (Kernel Hung/Panic).

3.  **Phase 3: Serial Debugging (Collaborative)**
    *   **Goal**: Capture boot logs to find bootloops or WiFi errors.
    *   **Agent Action**: Ask the user to connect the device via USB.
    *   **Agent Action**: Monitor the Serial Port (if capable) or ask user to provide logs.
        *   *Instruction*: "Please check the Serial Monitor at 115200 baud. Does it hang at 'Connecting to WiFi...'?"

## Common Resolutions & Fixes

*   **Symptom**: Node Stuck in "Unknown" in Peer List.
    *   *Cause*: mDNS announced existence, but HTTP Status Poll failed.
    *   *Agent Action*: Run a manual curl to check the endpoint: `curl -v http://[hostname].local/api/status`.

*   **Symptom**: Deployment Script says "OFFLINE".
    *   *Cause*: Windows PowerShell often fails to resolve `.local` domains during `Test-Connection` even if they work in the browser.
    *   *Agent Action*: Suggest replacing the hostname in `known_hosts.txt` with the raw IP address found in `arp -a`.

## Verification
*   User confirms LEDs are normal.
*   Agent successfully pings the node.
*   Agent successfully retrieves JSON from `/api/status`.

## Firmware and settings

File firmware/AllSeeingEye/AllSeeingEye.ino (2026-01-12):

#include "src/Kernel.h"
#include <WiFi.h>
#include <HTTPClient.h>

// Note: OTA Logic is temporarily removed during the restructure. 
// We will reintegrate it into the Kernel/WebServer in Phase 2/3.
// For now, upload via USB.

void setup() {
    // Initialize Serial here for earliest possible logging
    Serial.begin(115200);
    delay(1000); 

    // Handover to Kernel
    Kernel::instance().setup();
}

void loop() {
    Kernel::instance().loop();
}

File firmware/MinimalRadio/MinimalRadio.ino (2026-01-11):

#include <RadioLib.h>
#include <SPI.h>

SPIClass radioSPI(FSPI);
CC1101 radio = new Module(10, 4, RADIOLIB_NC, 5, radioSPI);

void setup() {
  Serial.begin(115200);
  radioSPI.begin(12, 13, 11, 10);
  int state = radio.begin();
  if (state == RADIOLIB_ERR_NONE) {
    Serial.println("Success!");
  } else {
    Serial.print("Failed: ");
    Serial.println(state);
  }
}

void loop() {}

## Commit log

2026-01-08 added initial versions
    [all-seeing-eye.1.0.scad, all-seeing-eye.1.0.stl, all-seeing-eye.1.1.scad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]
2026-01-10 created new renderings
    [all-seeing-eye.1.6.scad, assembly.1.0.scad, base-plate.1.0.scad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]
2026-01-10 added additional assets and build files
    [all-seeing-eye.1.0.stl, all-seeing-eye.1.1.stl, all-seeing-eye.1.2.stl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]
2026-01-11 added wiring diagram and initial firmware with ota pipeline and scripts
    [all-seeing-eye.1.0.stl, all-seeing-eye.1.1.stl, all-seeing-eye.1.2.stl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]
2026-01-11 migrate firmware to new kernel structure and build initial framework, update roadmap.
2026-01-11 update print preview and print statistics for new hardware revision
2026-01-11 complete radio drivers and self-test
2026-01-12 set up initial clustering framework and mdns peer discovery
2026-01-12 reorganized models pipeline within a subdirectory in order to create agentic playbook pipeline with common hierarchical structure for the different branches of the project.
    [all-seeing-eye.1.0.scad, all-seeing-eye.1.0.stl, all-seeing-eye.1.1.scad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]
2026-01-12 at some point, the build folder was renamed to 3d models for some reason, so it contained build artifacts
    [partitions.csv]
2026-01-14 Expanded kernel scheduler, added reboot and log head endpoints, added auto-refresh in webui when build number changes
    [Kernel.cpp]
2026-01-14 built geolocation plan/framework
2026-01-15 Added LED controls to api
2026-01-15 added ntp time synchronization and initial python api library for testing and validating features
    [known_hosts.csv]

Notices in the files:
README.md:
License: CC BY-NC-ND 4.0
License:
